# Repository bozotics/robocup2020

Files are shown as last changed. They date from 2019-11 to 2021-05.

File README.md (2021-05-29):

## PCB Design Files

View .sch and .brd files interactively on [Inventhub!](https://inventhub.io/c/bozotics/robocup2020/tree/PCB)   

Included in this repo are design files for the various PCBs we use. We designed these in EAGLE thanks to [Autodesk's free education licences](https://www.autodesk.com/education/free-software/featured). 

The libraries used unfortunately cannot be shared due to Autodesk's library.io sharing limitations, however if you would like to view it do contact us! We would be happy to send a copy of the latest version, albeit without the included 3d models (again due to the library.io limitations).

Structure of this repository:
```
.
├── Datasheets # PDFs for the various parts we use
├── PCB2k20 # Design files for our PCBs
│   ├── Layer 1, 3, 4 # for Soccer Open
│   ├── PMW3360MouseSensor # for our Mouse Sensor breakout board
│   ├── RescueLS # for Rescue Line's light sensor breakout board
│   └── TPS5430 # for the buck converter breakout board
├── TestV3_2020
└── Rescue
```
Files for previous years can be found in our [other archived repositories](https://github.com/bozotics).

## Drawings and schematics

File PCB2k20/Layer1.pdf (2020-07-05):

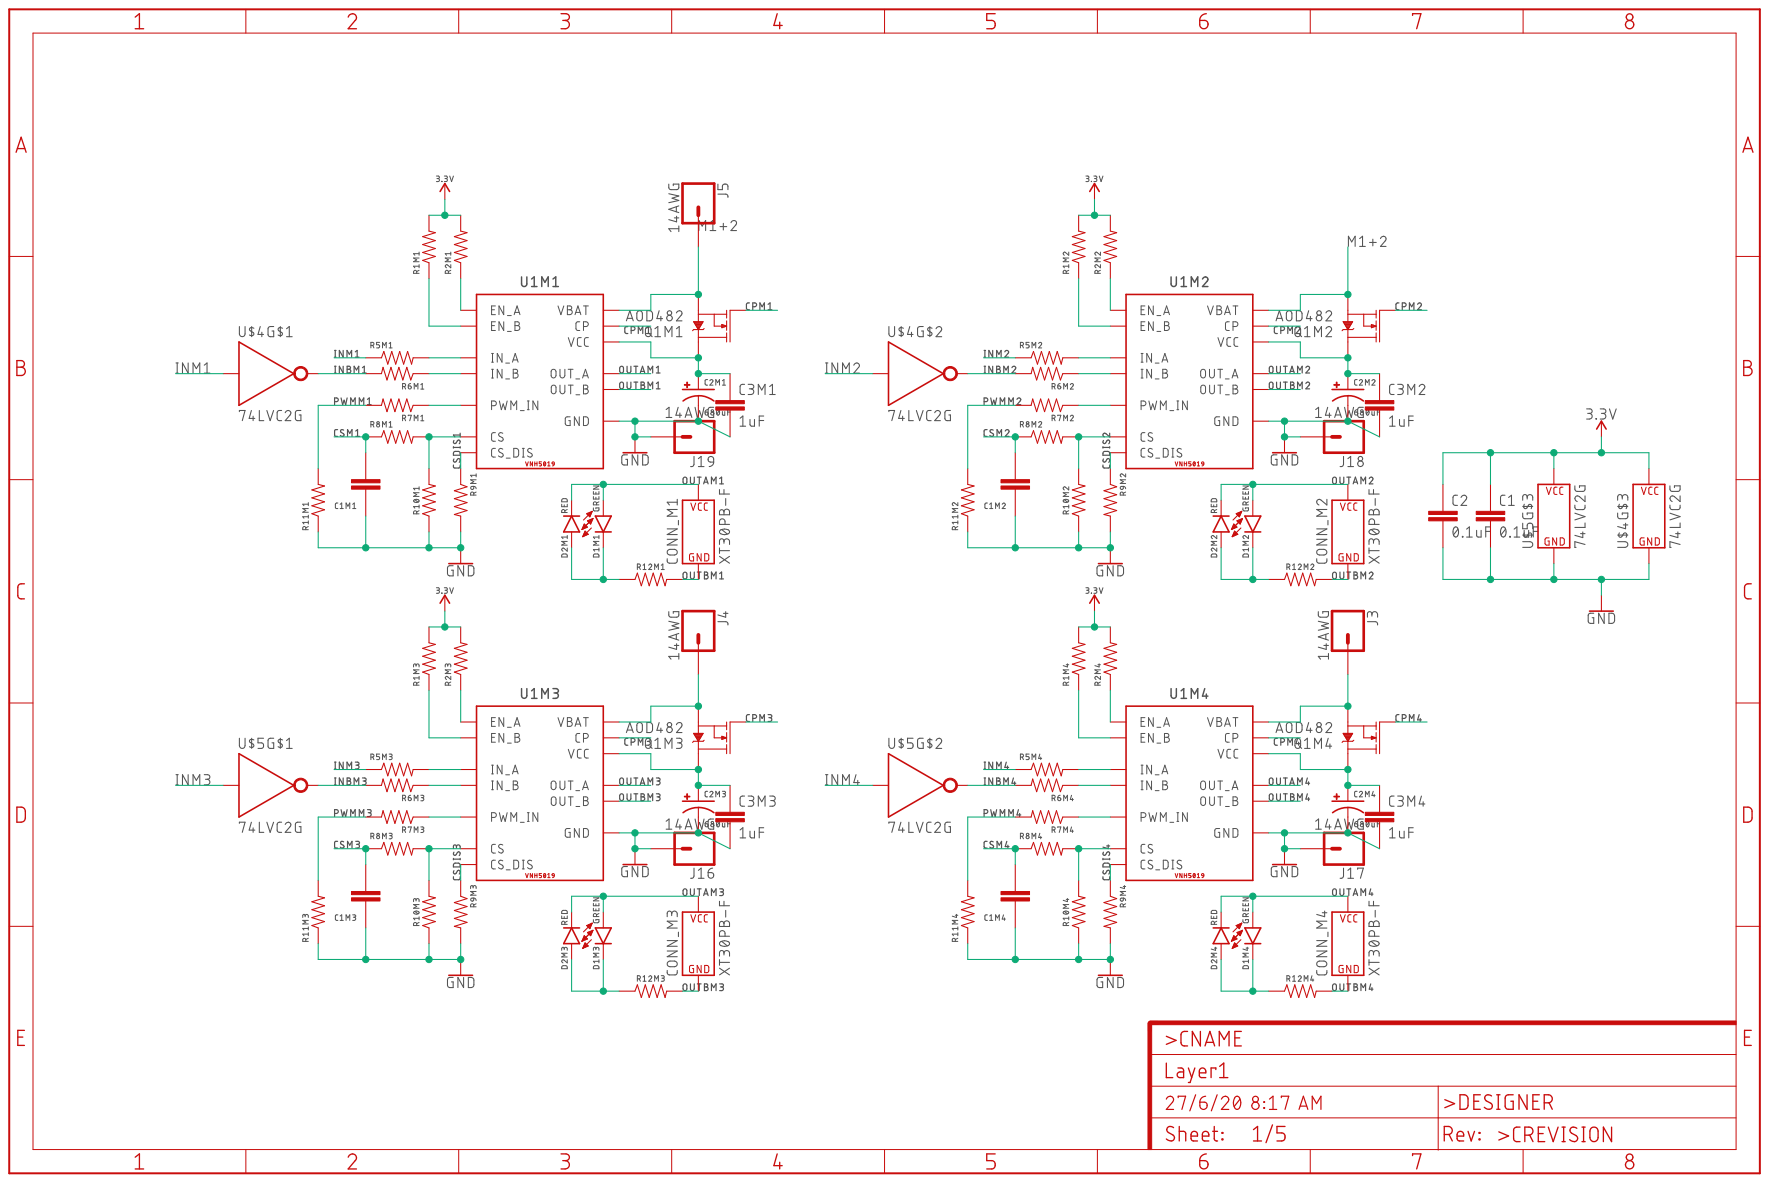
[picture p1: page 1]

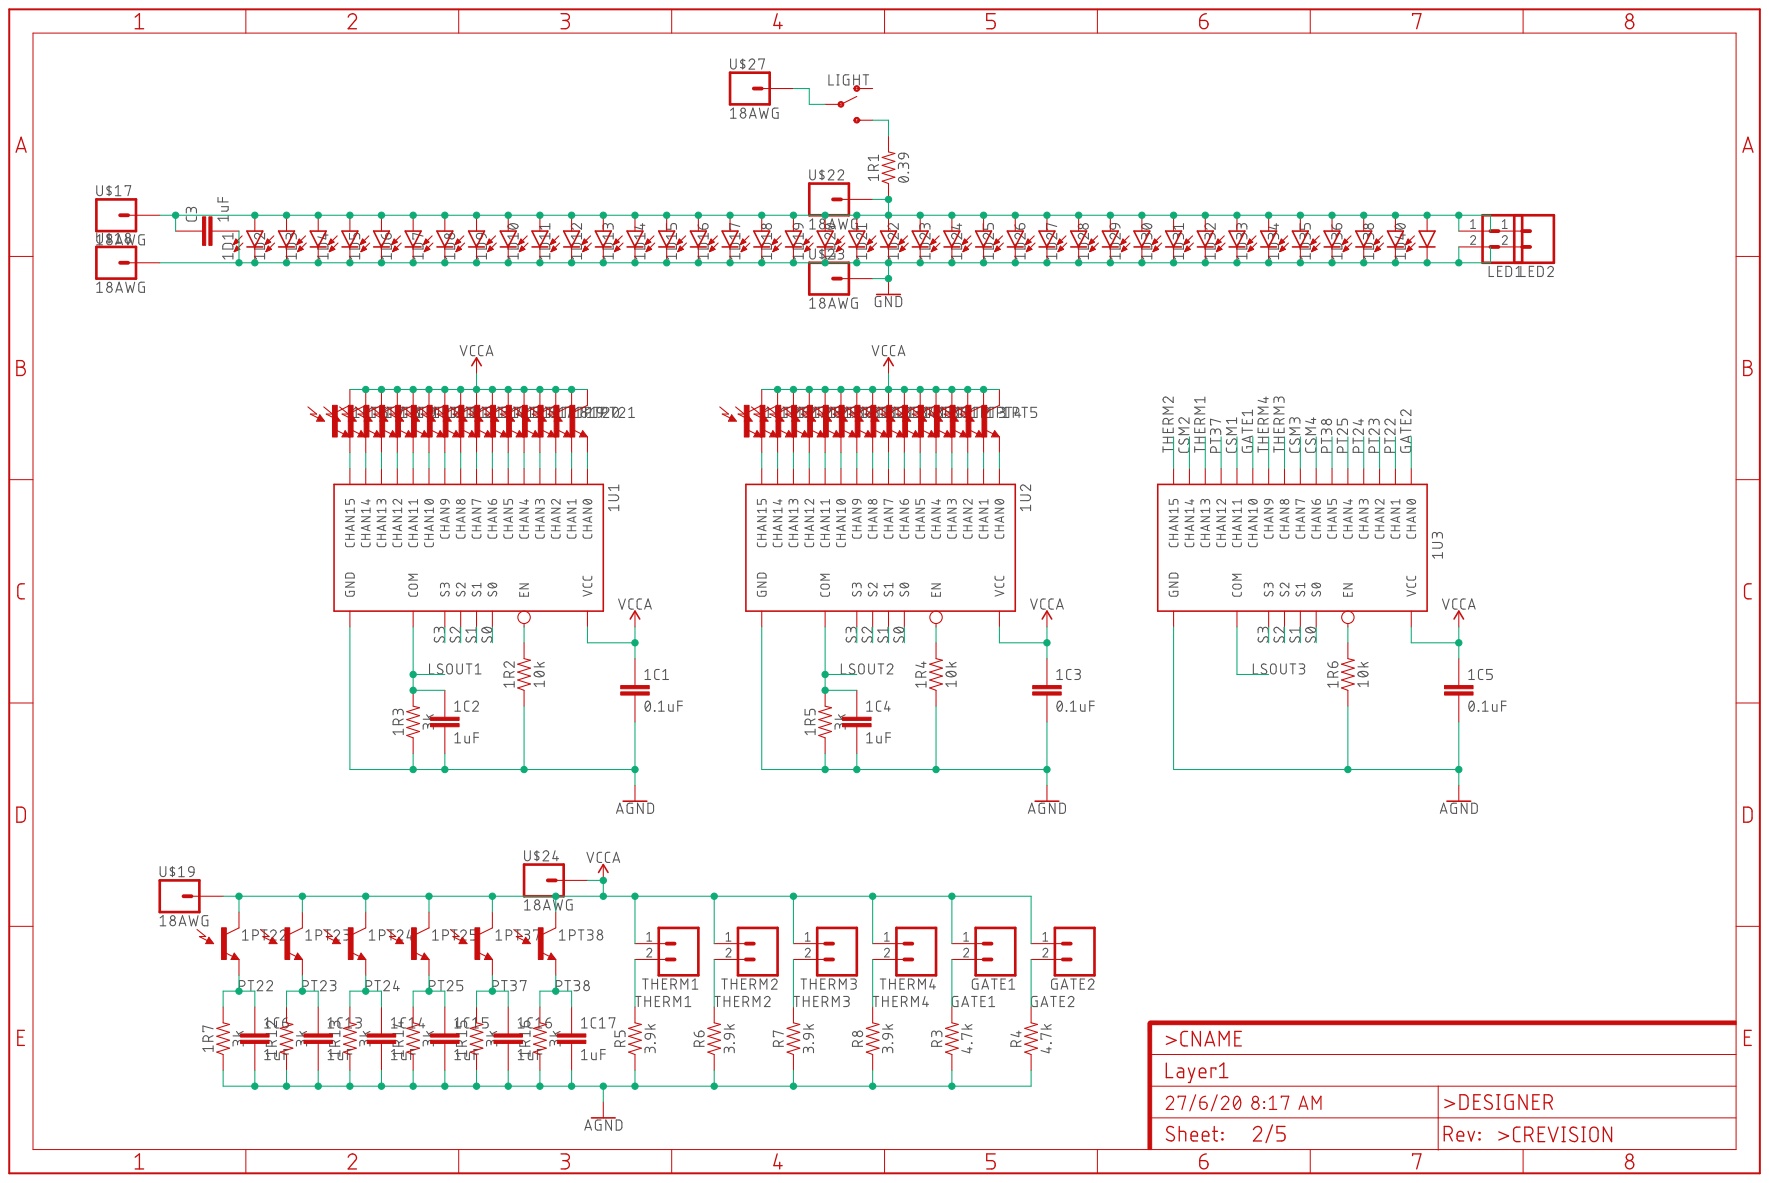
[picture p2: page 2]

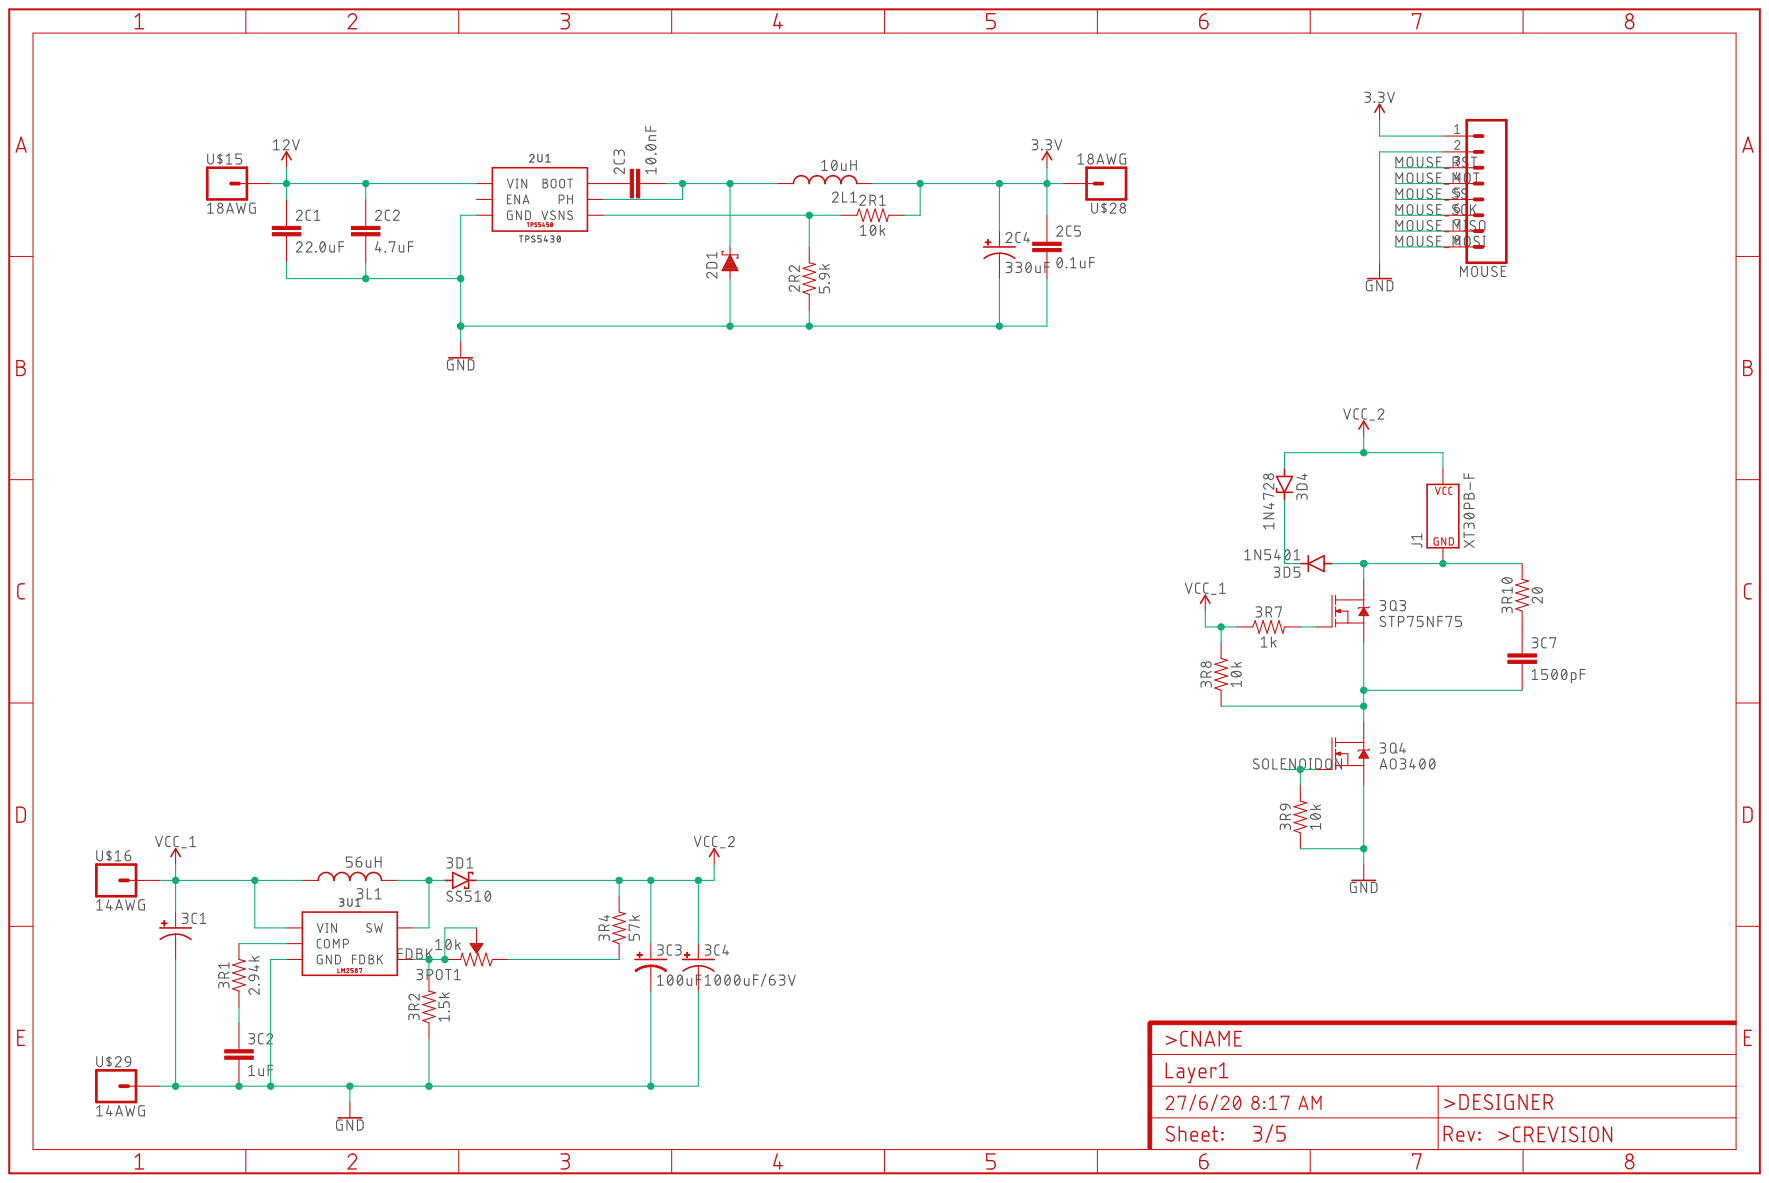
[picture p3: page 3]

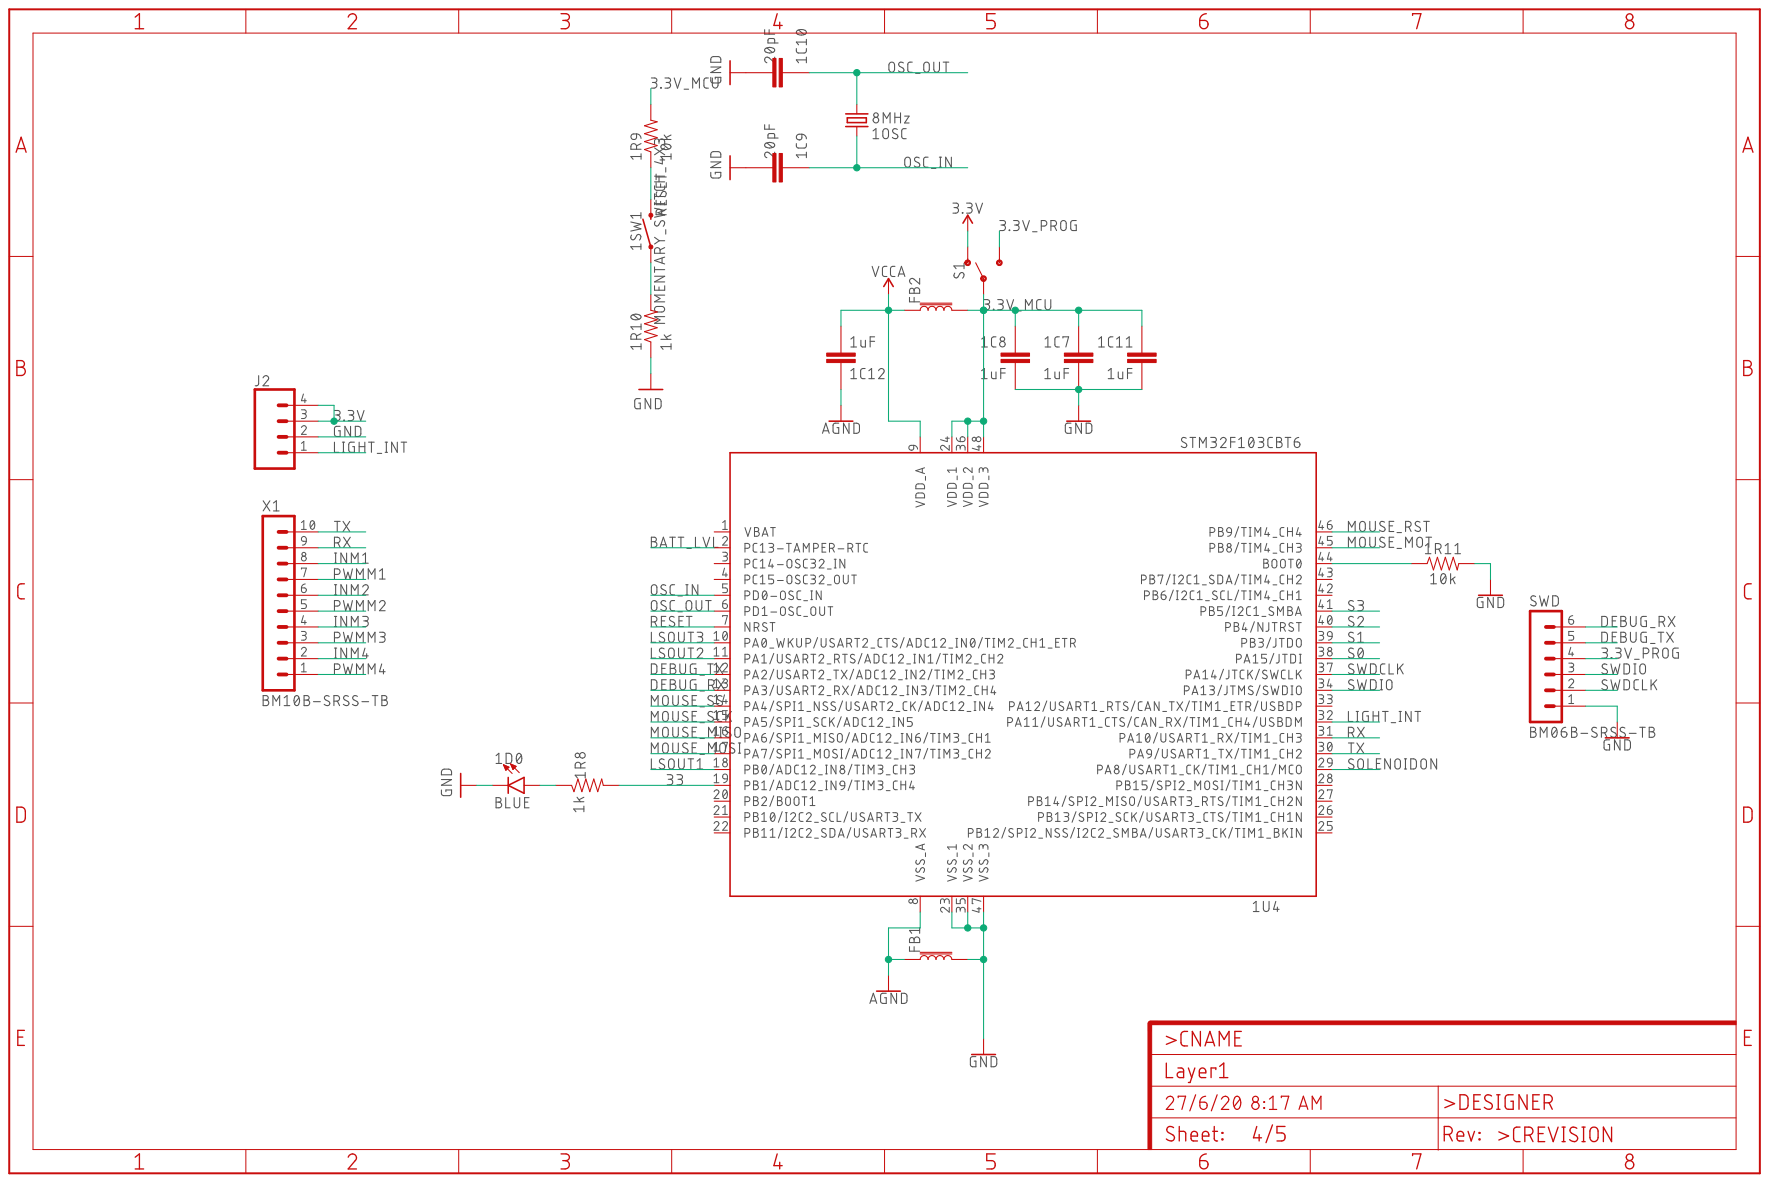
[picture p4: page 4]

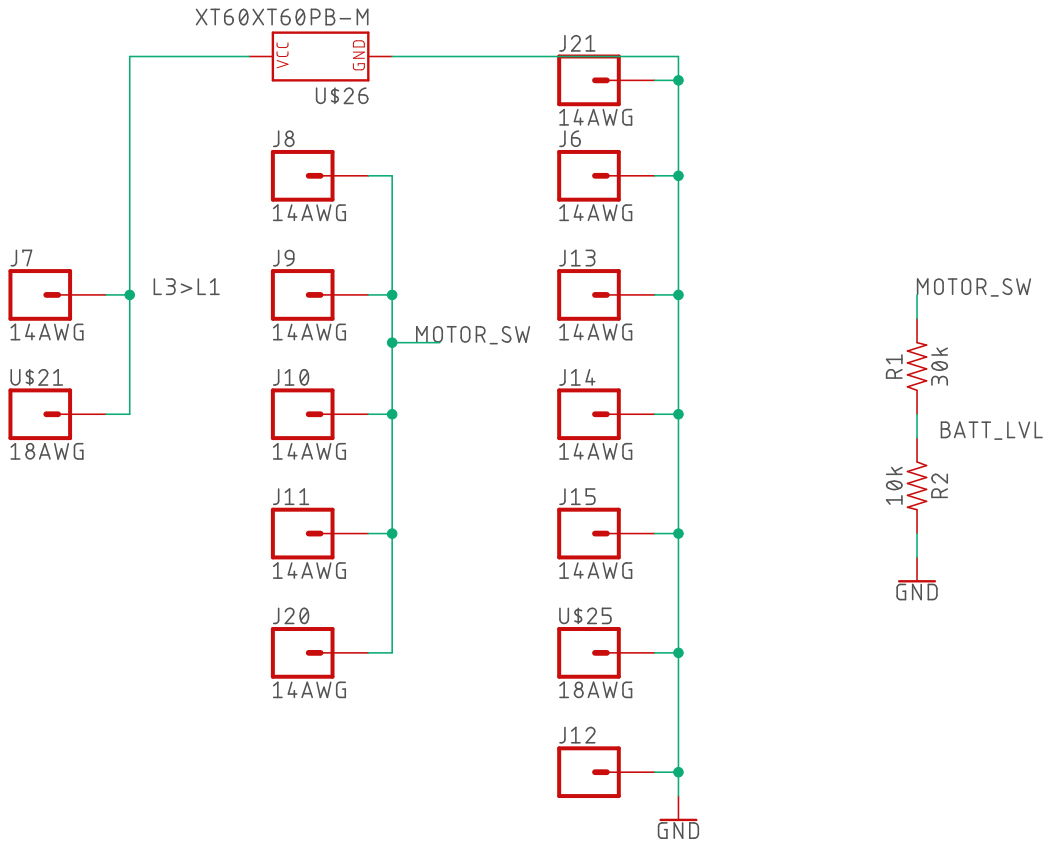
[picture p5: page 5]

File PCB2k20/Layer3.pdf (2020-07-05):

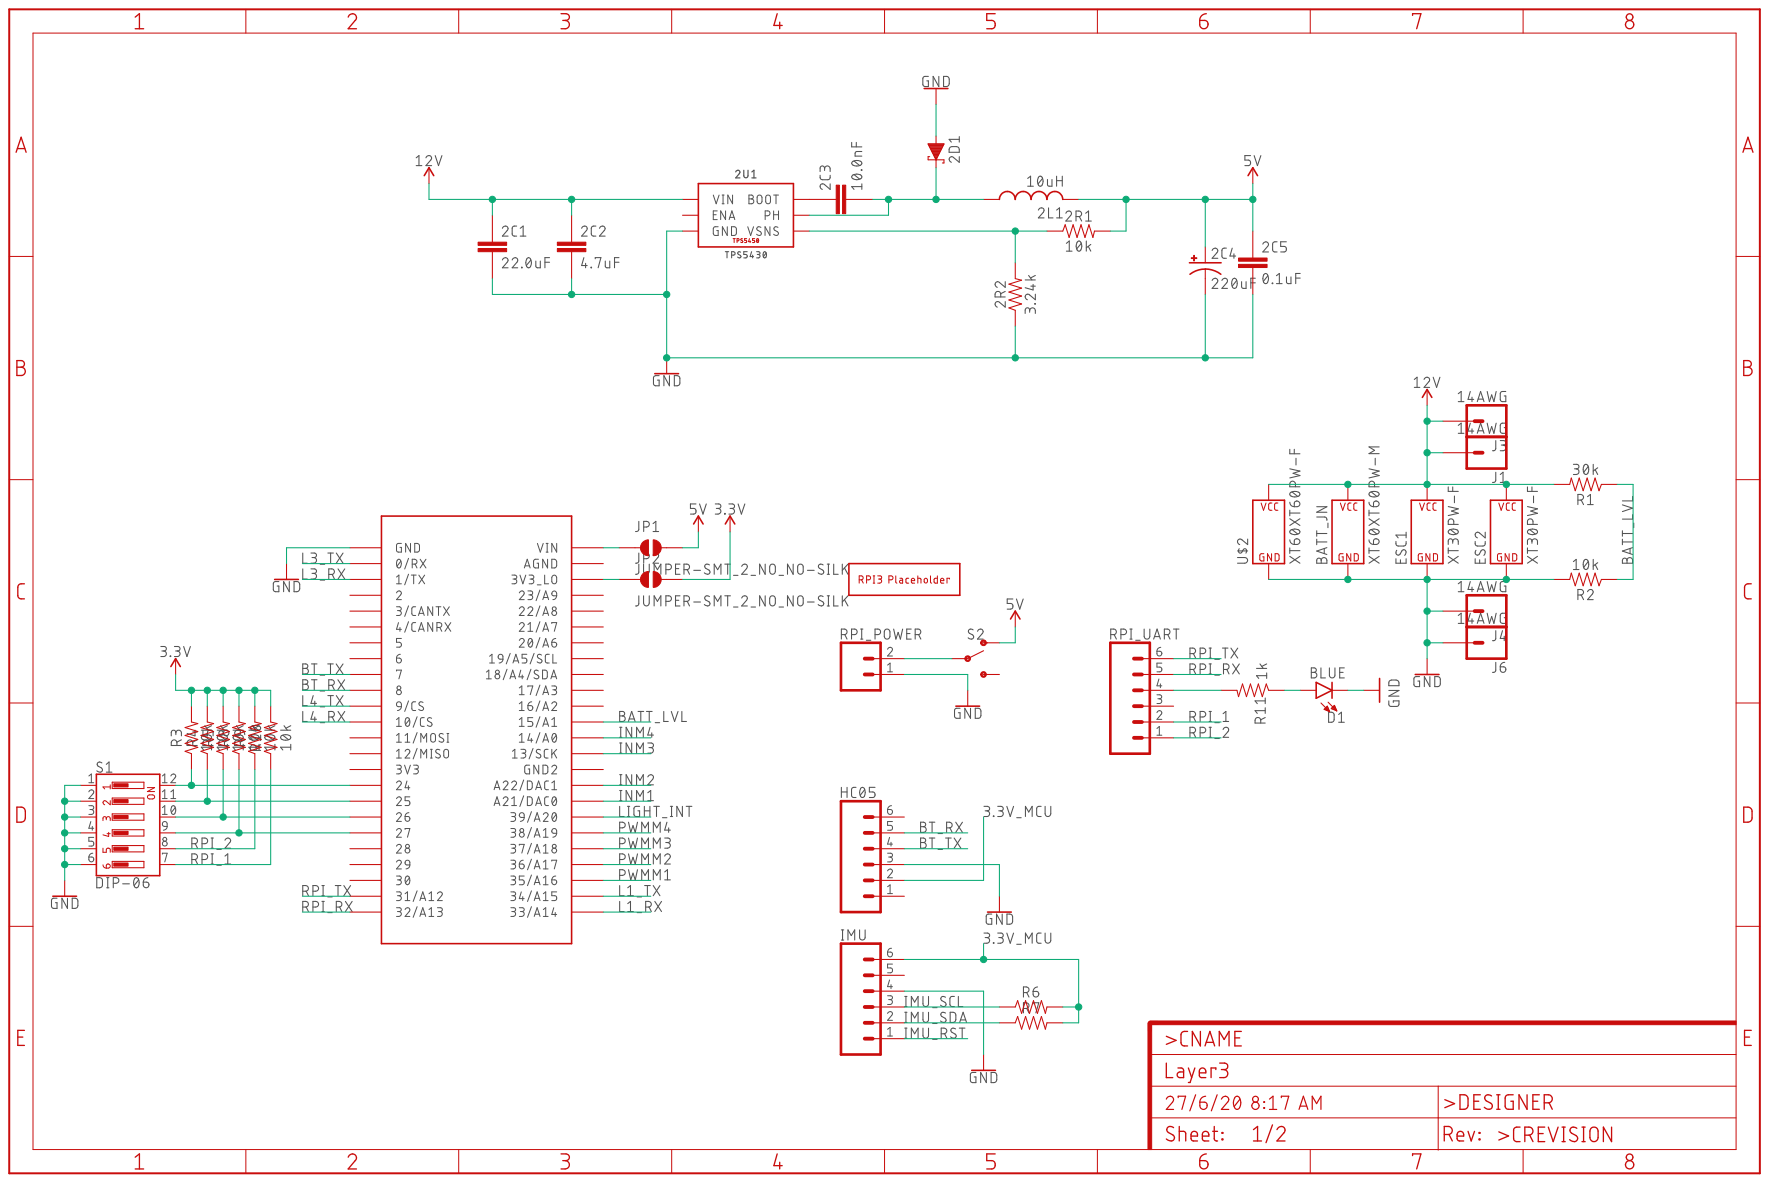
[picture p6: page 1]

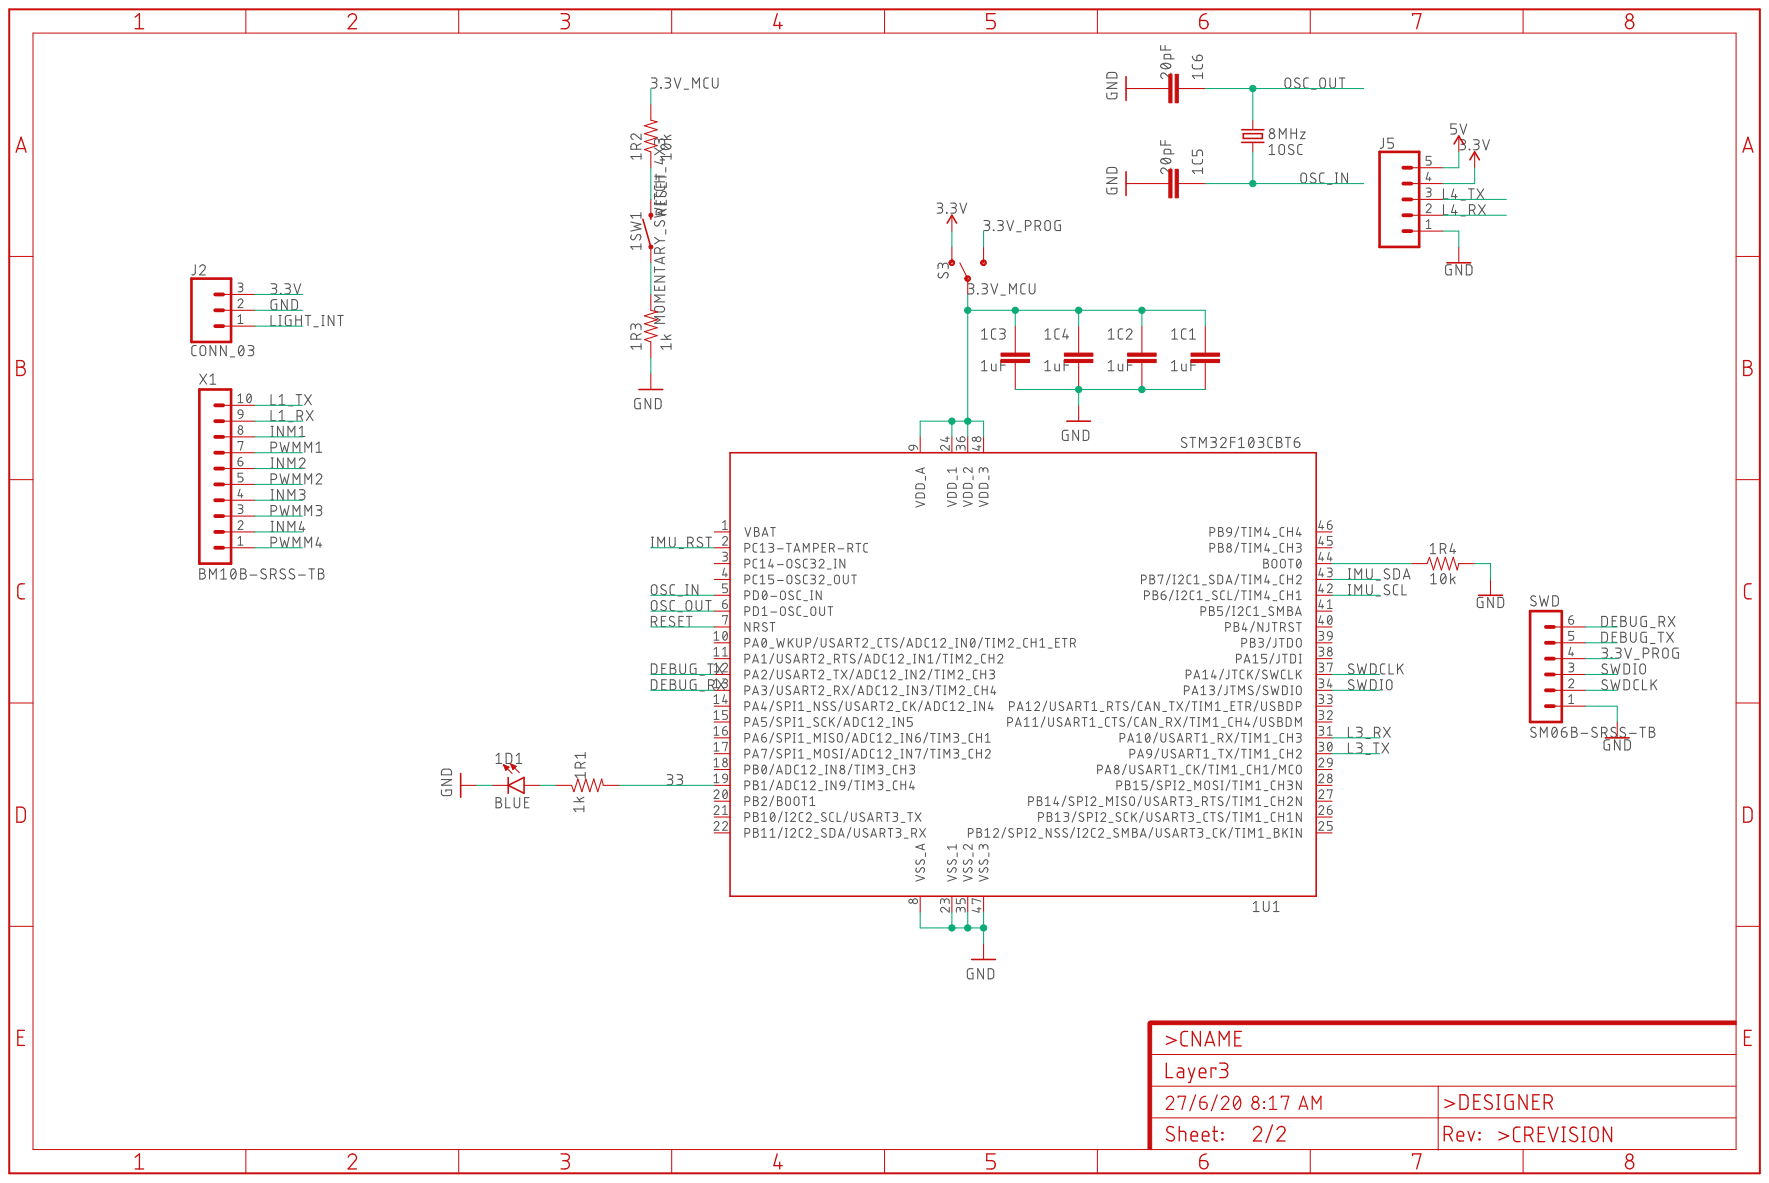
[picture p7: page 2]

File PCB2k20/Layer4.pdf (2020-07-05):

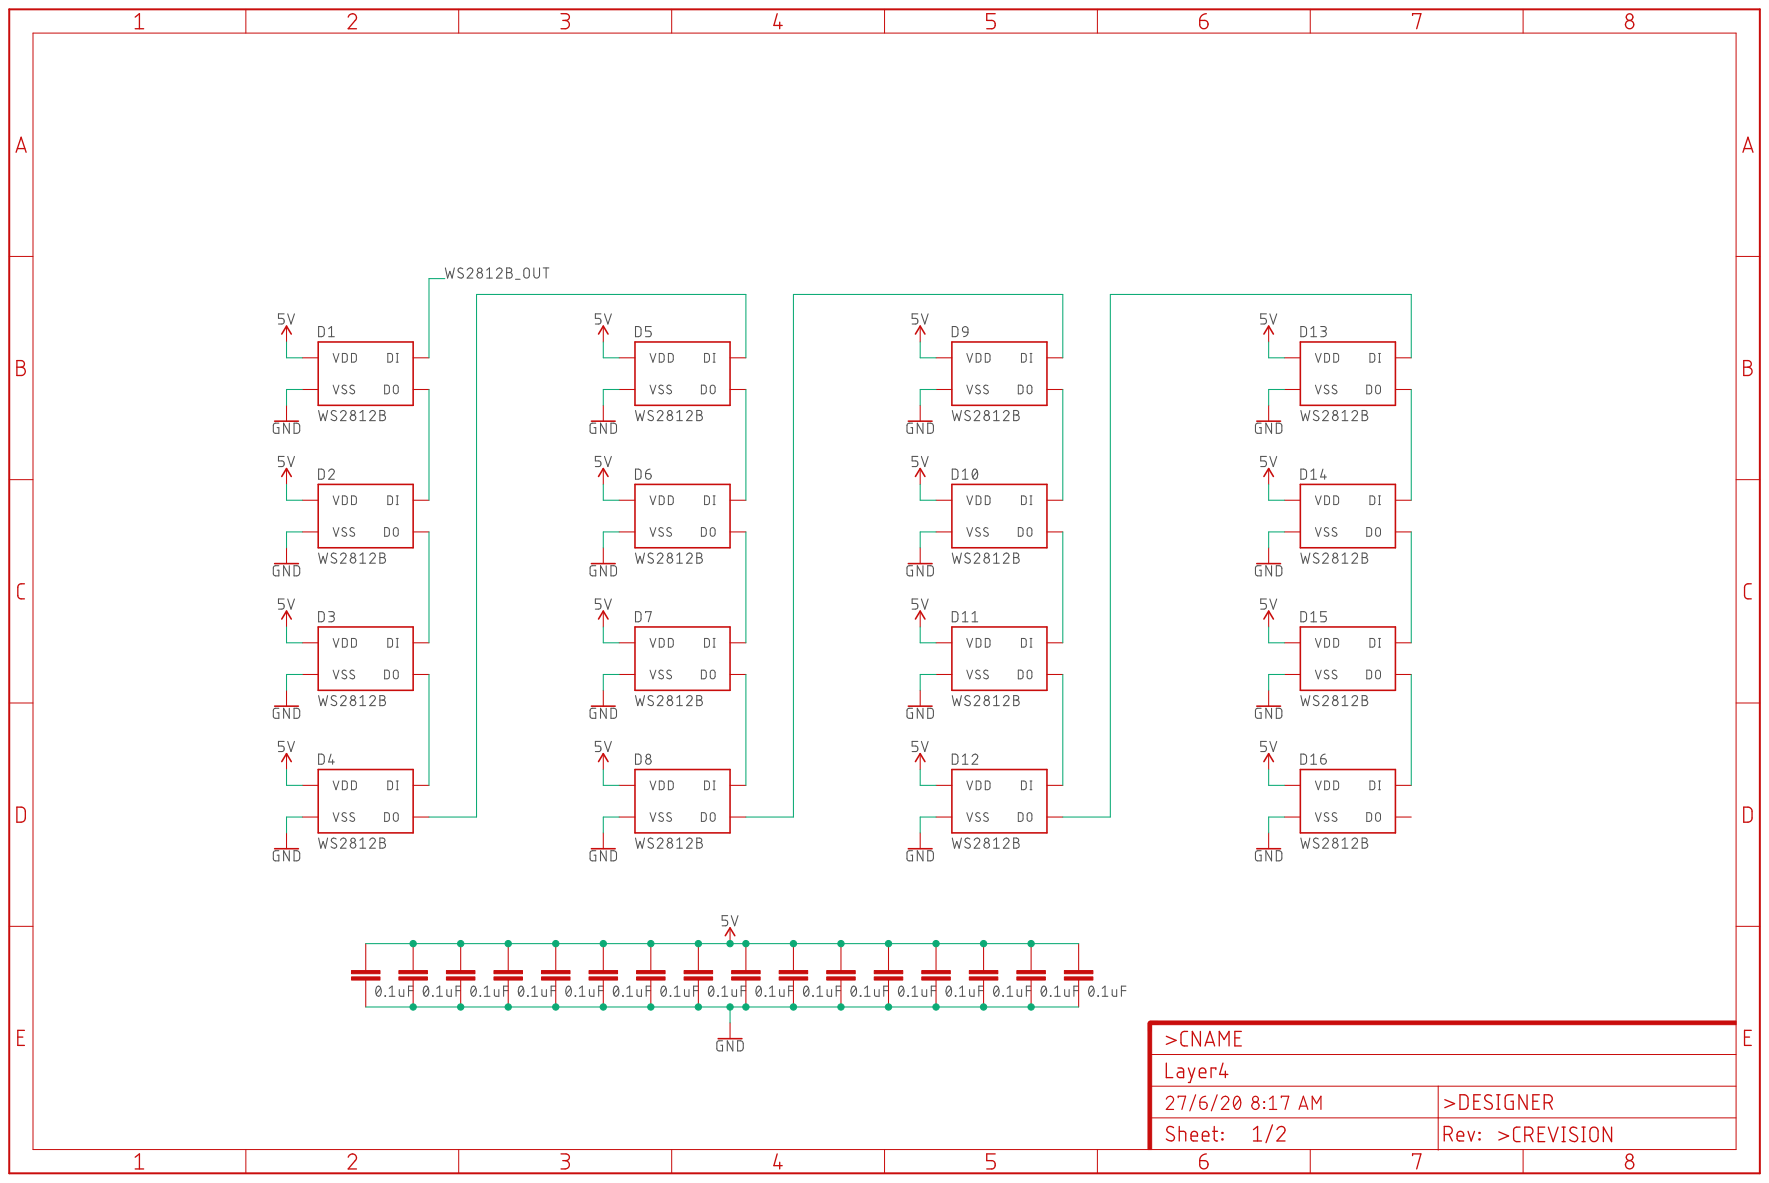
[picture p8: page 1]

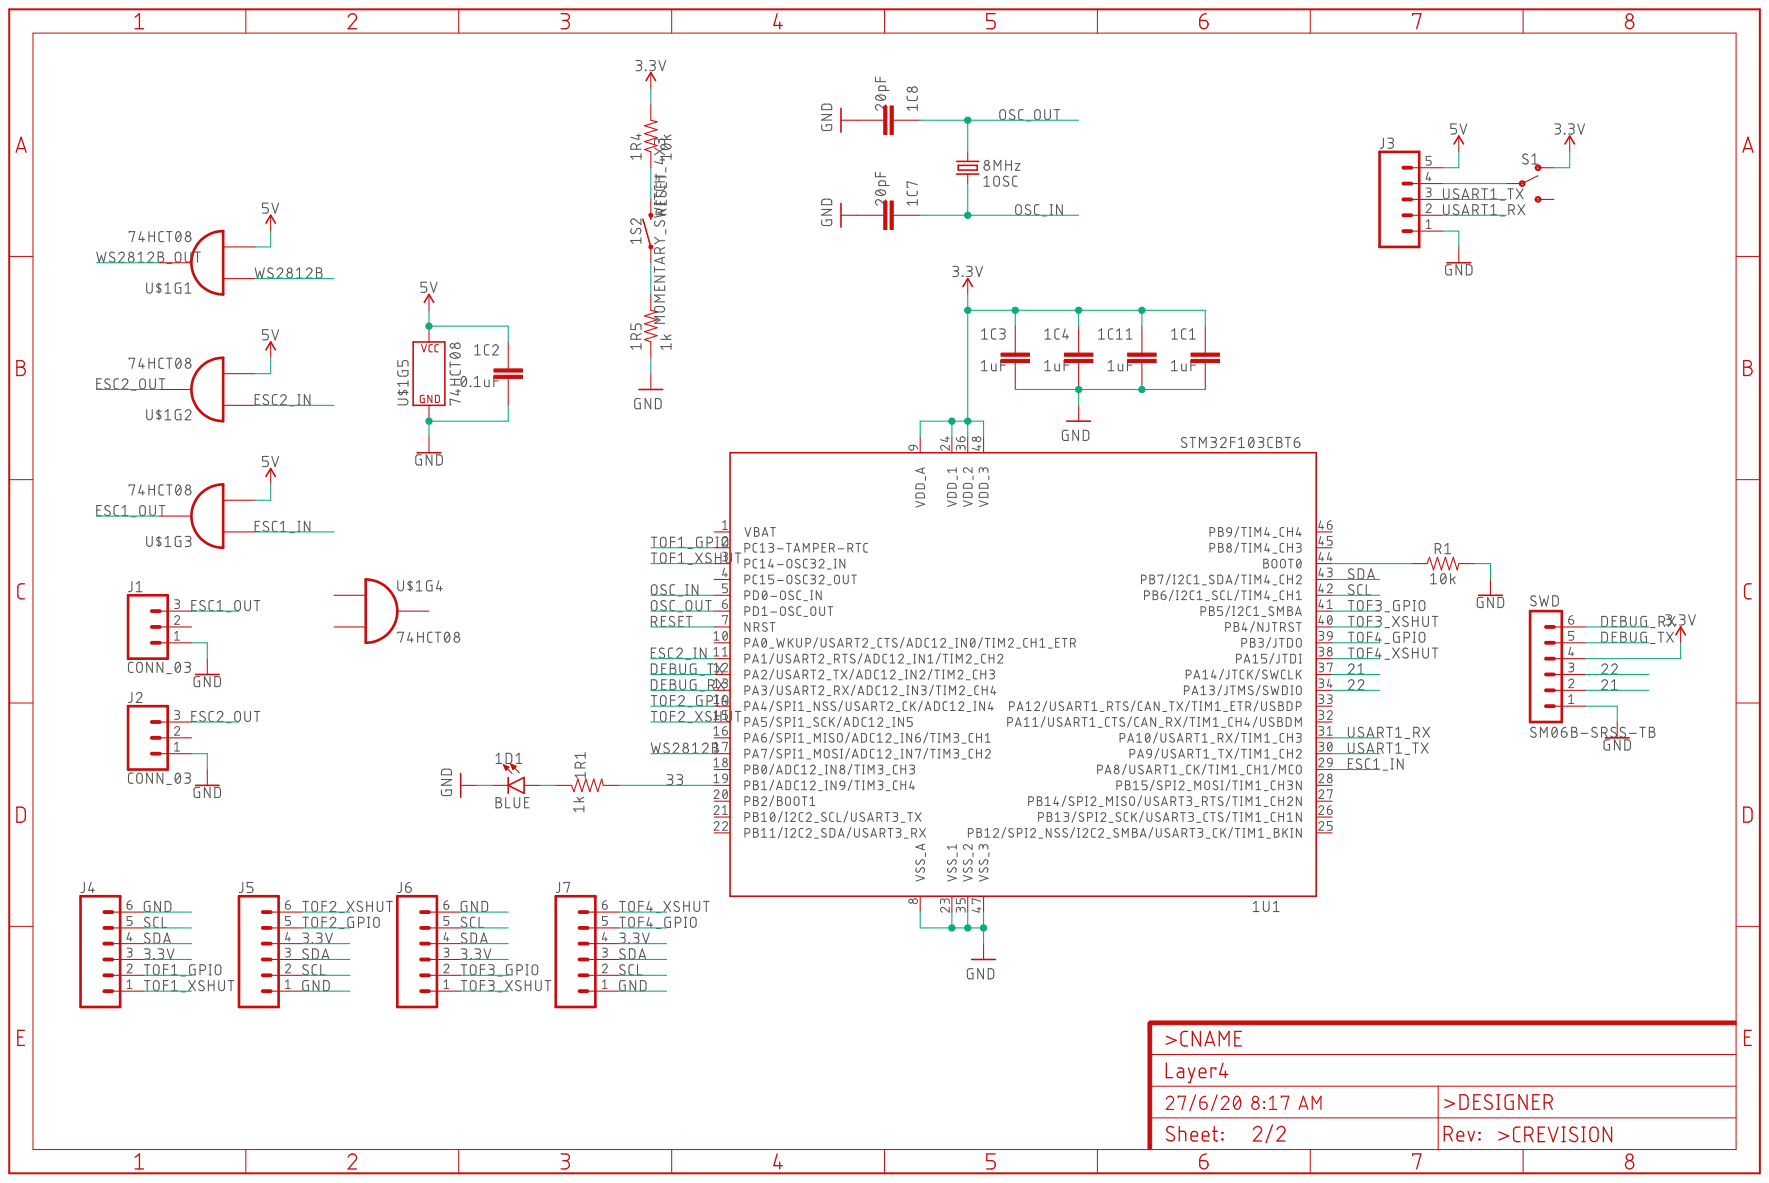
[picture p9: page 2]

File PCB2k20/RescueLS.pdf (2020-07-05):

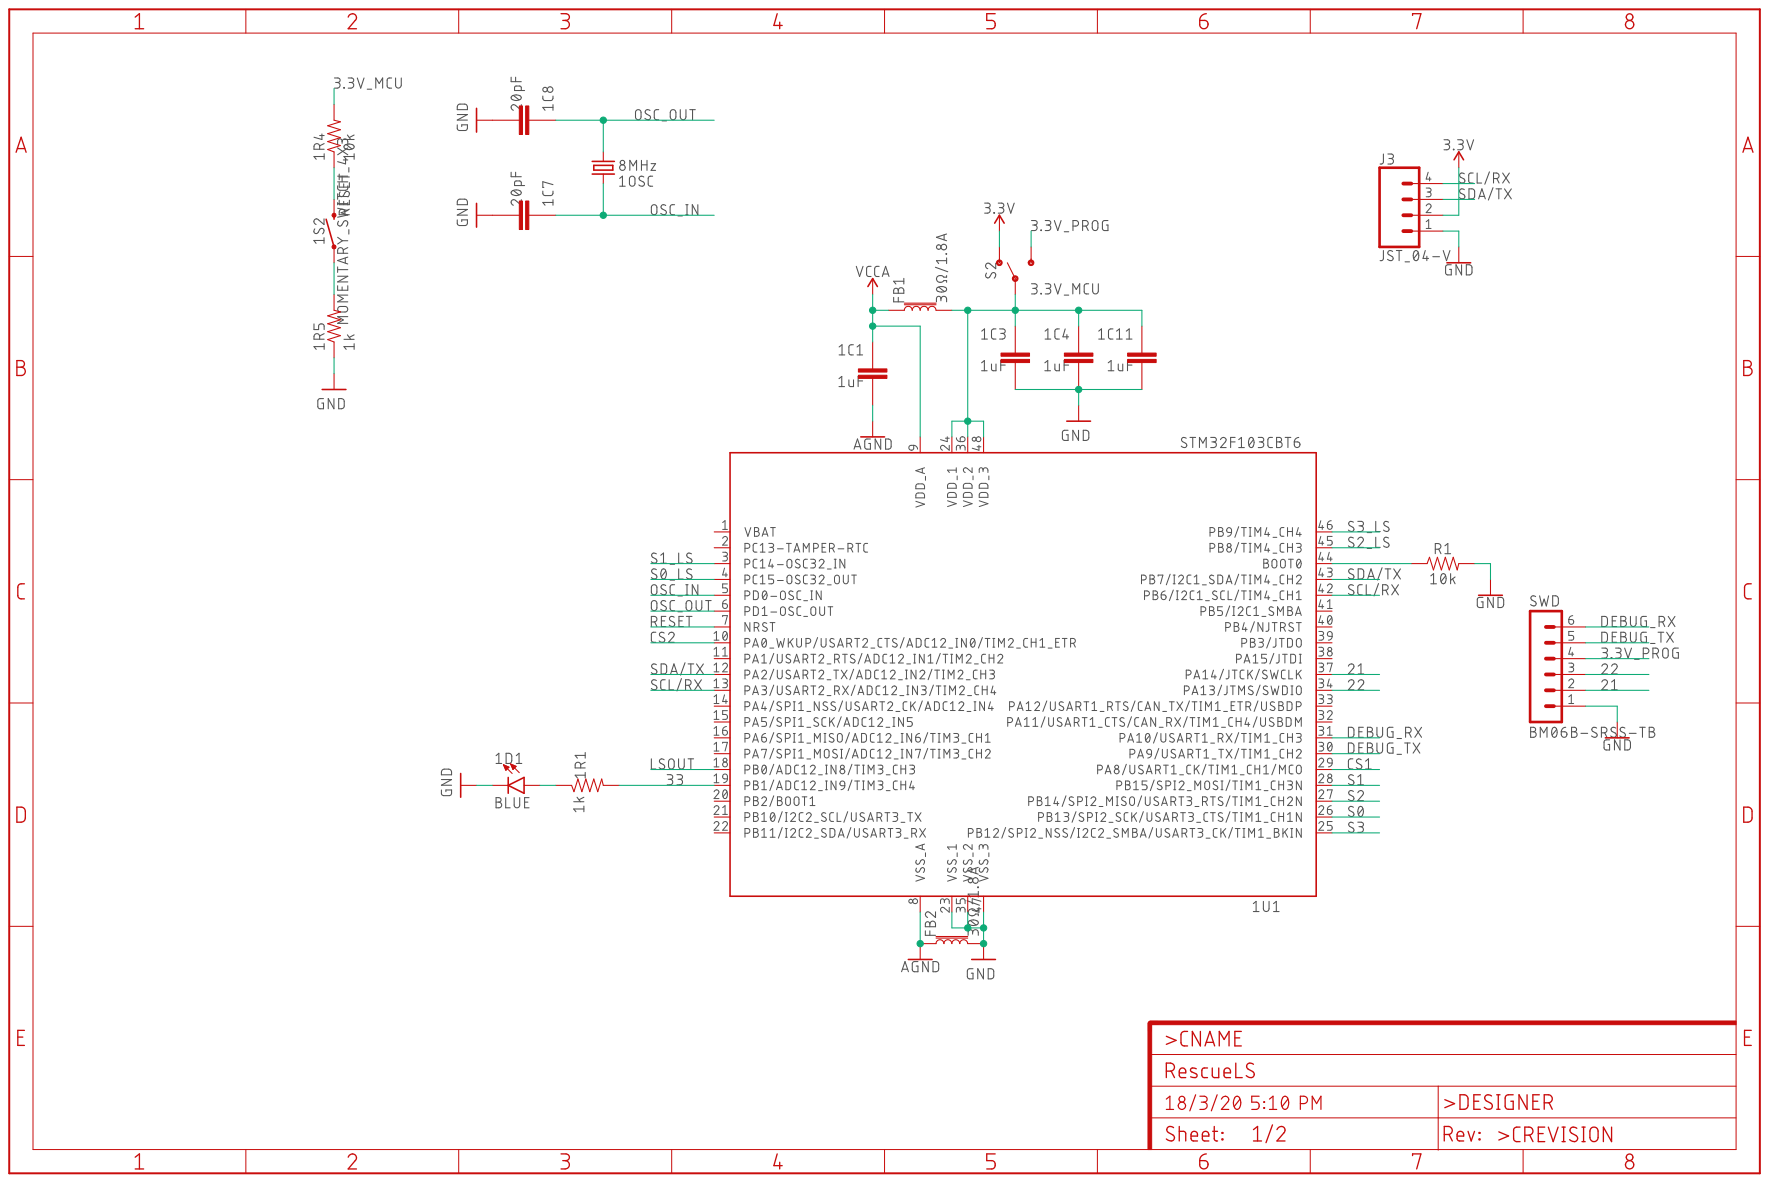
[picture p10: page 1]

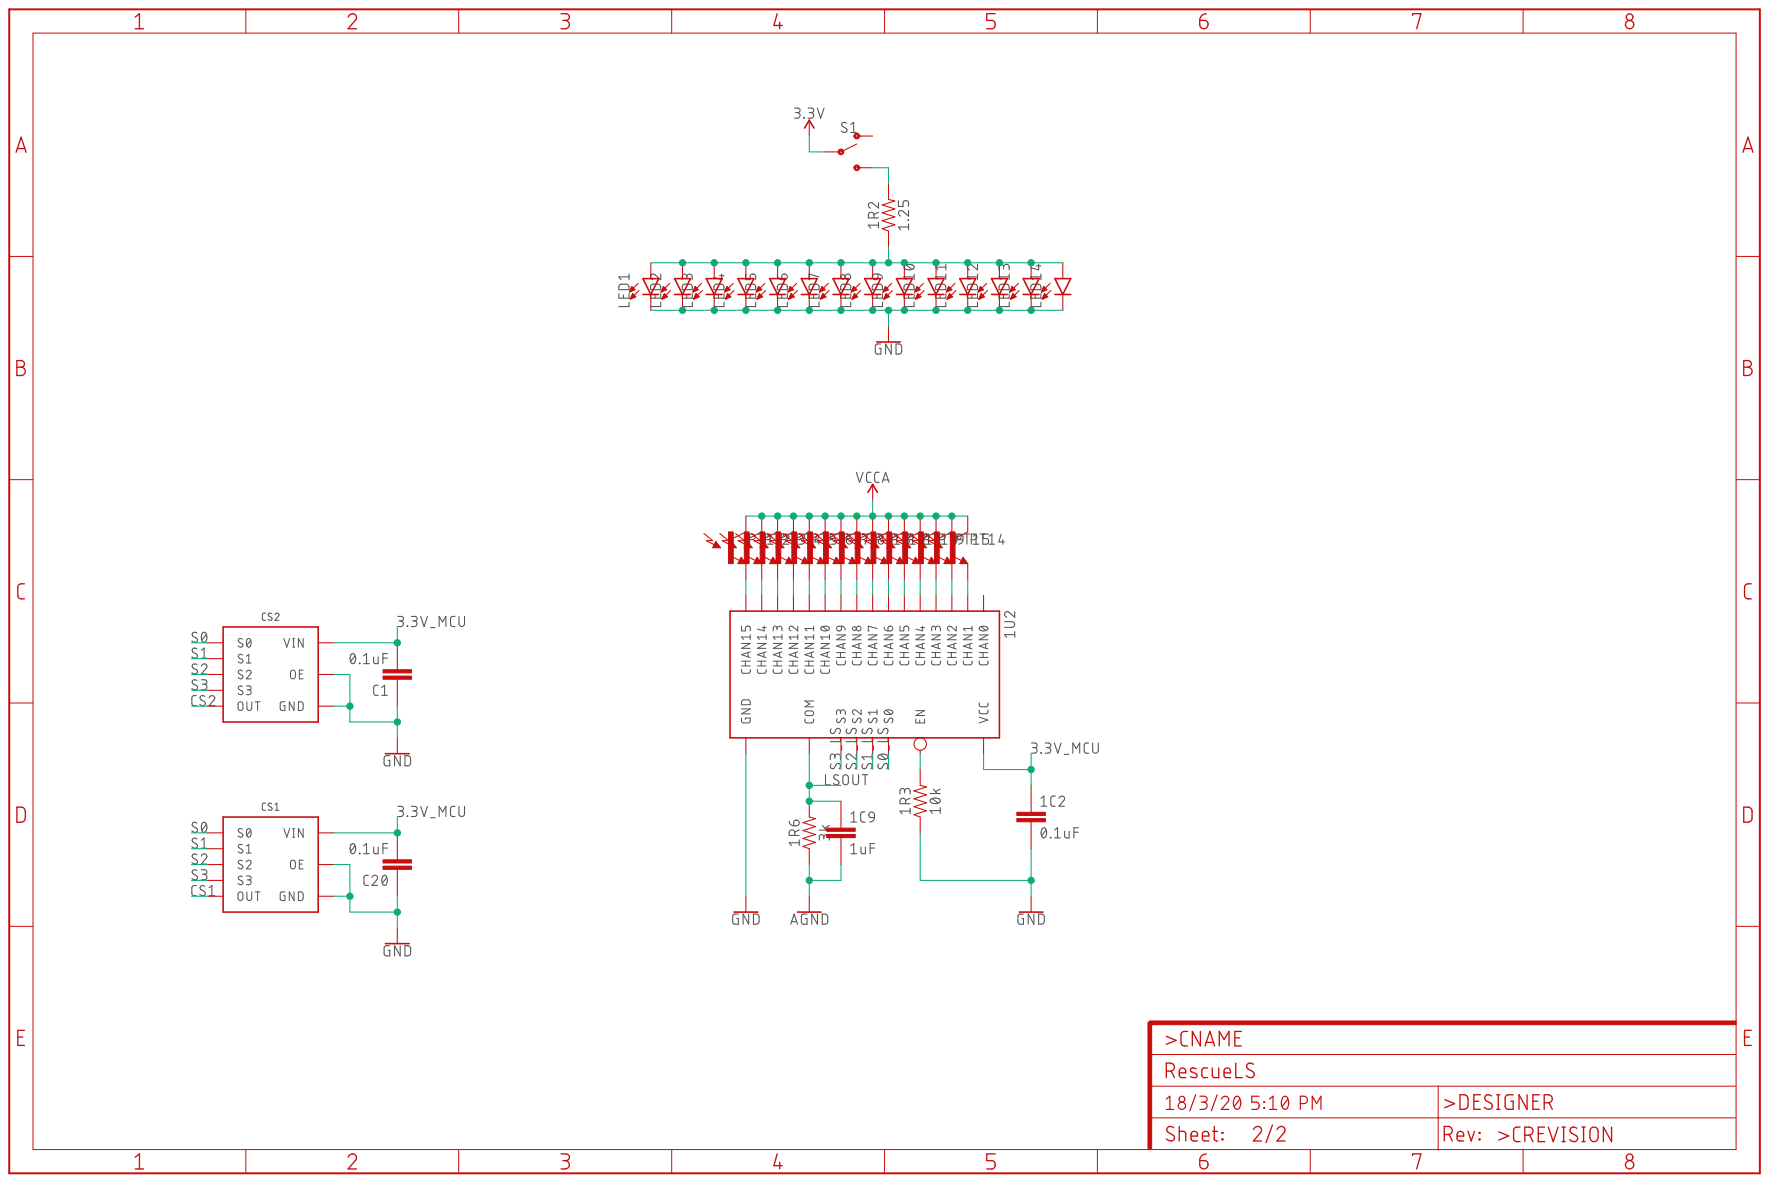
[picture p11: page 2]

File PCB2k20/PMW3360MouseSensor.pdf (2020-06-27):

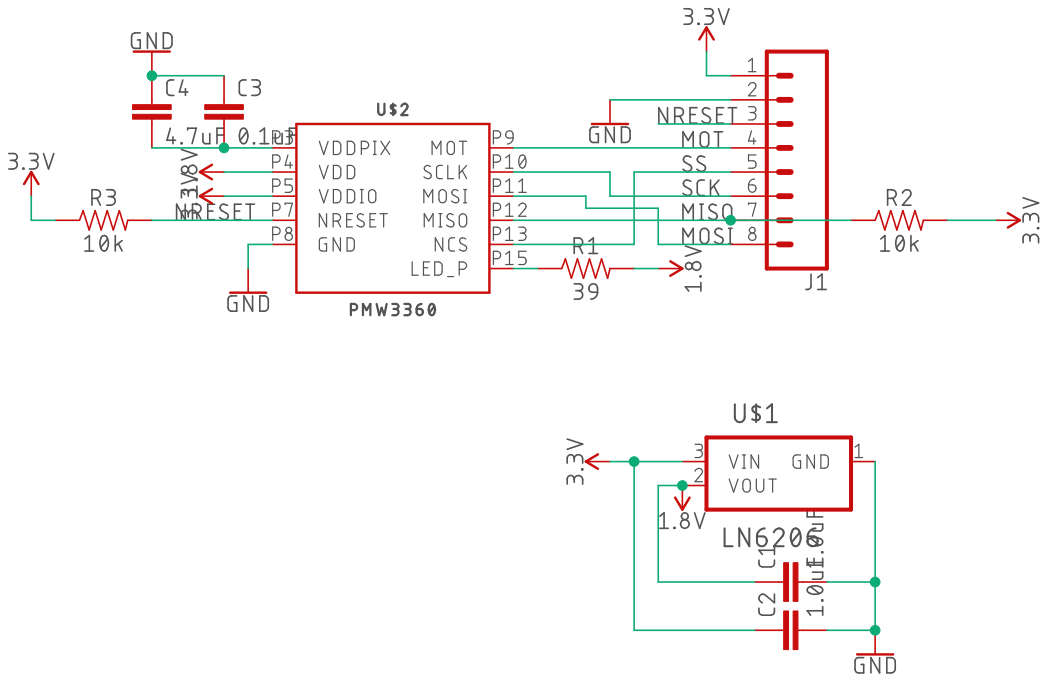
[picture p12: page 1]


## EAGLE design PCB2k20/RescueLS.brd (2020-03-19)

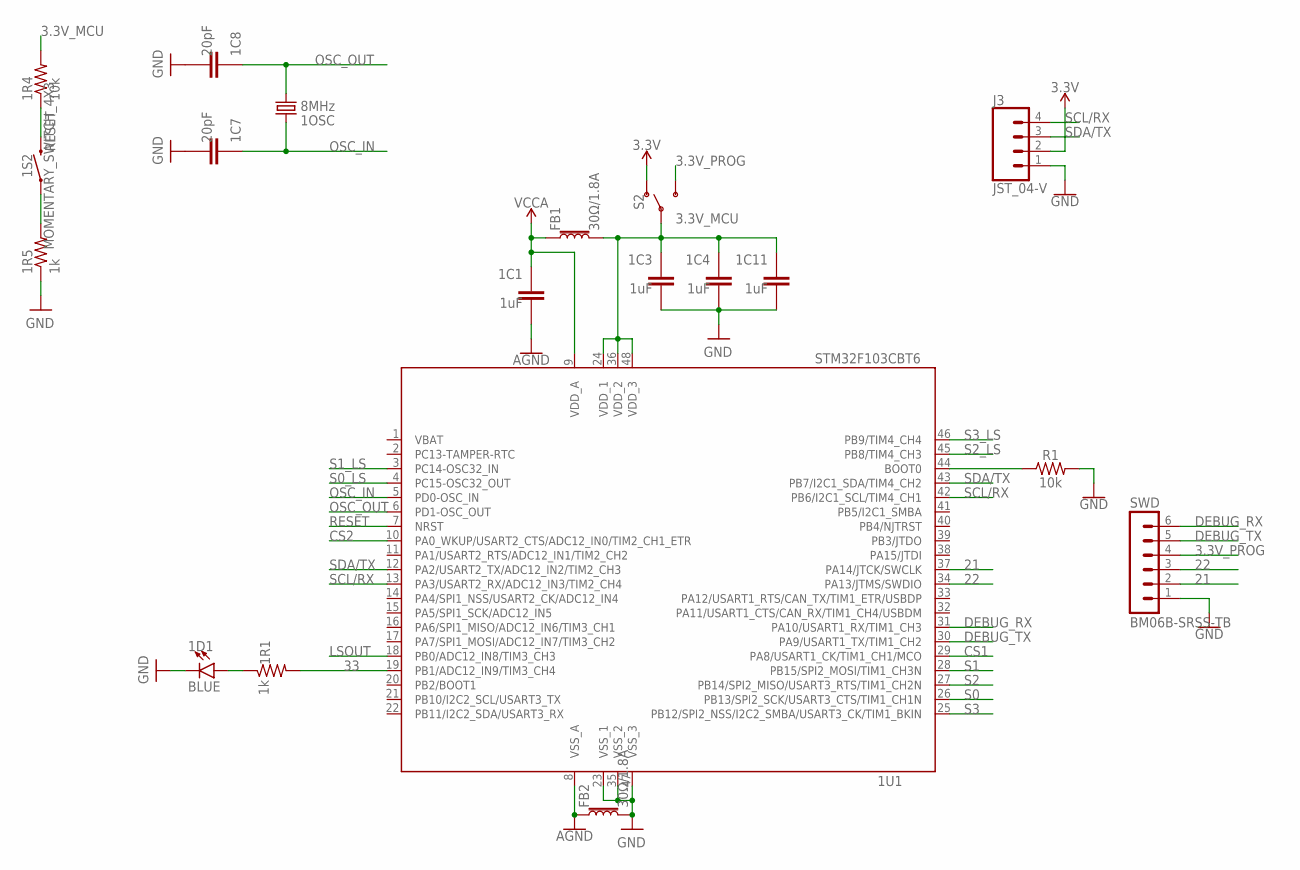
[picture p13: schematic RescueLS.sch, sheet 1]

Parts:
1C1, 1C3, 1C4, 1C11: 1uF; C0603
1C7, 1C8: 20pF; C0603
1D1: BLUE; LED-0603
1OSC: 8MHz; CRYSTAL-SMD-5X3.2-2PAD
1R1, 1R5: 1k; R0603
1R4: 10k; R0603
1S2: MOMENTARY_SWITCH_4X3
1U1: STM32F103CBT6; LQFP48
FB1, FB2: 30Ω/1.8A; 0603
J3: JST_04-V
R1: 10k; R0603
S2: SWITCH-SPDT-PTH-11.6X4.0MM-LOCK; SWITCH_SPDT_PTH_11.6X4.0MM_LOCK
SWD: BM06B-SRSS-TB

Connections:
3.3V: J3.2, S2.1 (O); also elsewhere on the board
3.3V_MCU: 1C3.1, 1C4.1, 1C11.1, 1R4.2, 1U1.24 (VDD_1), 1U1.36 (VDD_2), 1U1.48 (VDD_3), FB1.2, S2.2; also elsewhere on the board
3.3V_PROG: S2.3 (S), SWD.4
21: 1U1.37 (PA14/JTCK/SWCLK), SWD.2
22: 1U1.34 (PA13/JTMS/SWDIO), SWD.3
33: 1R1.2, 1U1.19 (PB1/ADC12_IN9/TIM3_CH4)
AGND: 1C1.2, 1U1.8 (VSS_A), FB2.1; also elsewhere on the board
CS1: 1U1.29 (PA8/USART1_CK/TIM1_CH1/MCO); also elsewhere on the board
CS2: 1U1.10 (PA0_WKUP/USART2_CTS/ADC12_IN0/TIM2_CH1_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); also elsewhere on the board
DEBUG_RX: 1U1.31 (PA10/USART1_RX/TIM1_CH3), SWD.6
DEBUG_TX: 1U1.30 (PA9/USART1_TX/TIM1_CH2), SWD.5
GND: 1C3.2, 1C4.2, 1C7.2, 1C8.2, 1C11.2, 1D1.C, 1R5.1, 1U1.23 (VSS_1), 1U1.35 (VSS_2), 1U1.47 (VSS_3), FB2.2, J3.1, R1.2, SWD.1; also elsewhere on the board
LSOUT: 1U1.18 (PB0/ADC12_IN8/TIM3_CH3); also elsewhere on the board
unnamed: 1D1.A, 1R1.1
unnamed: 1R5.2, 1S2.P$1 (1)
unnamed: 1U1.44 (BOOT0), R1.1
OSC_IN: 1C7.1, 1OSC.P$2 (2), 1U1.5 (PD0-OSC_IN)
OSC_OUT: 1C8.1, 1OSC.P$1 (1), 1U1.6 (PD1-OSC_OUT)
RESET: 1R4.1, 1S2.P$2 (2), 1U1.7 (NRST)
S0: 1U1.26 (PB13/SPI2_SCK/USART3_CTS/TIM1_CH1N); also elsewhere on the board
S0_LS: 1U1.4 (PC15-OSC32_OUT); also elsewhere on the board
S1: 1U1.28 (PB15/SPI2_MOSI/TIM1_CH3N); also elsewhere on the board
S1_LS: 1U1.3 (PC14-OSC32_IN); also elsewhere on the board
S2: 1U1.27 (PB14/SPI2_MISO/USART3_RTS/TIM1_CH2N); also elsewhere on the board
S2_LS: 1U1.45 (PB8/TIM4_CH3); also elsewhere on the board
S3: 1U1.25 (PB12/SPI2_NSS/I2C2_SMBA/USART3_CK/TIM1_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); also elsewhere on the board
S3_LS: 1U1.46 (PB9/TIM4_CH4); also elsewhere on the board
SCL/RX: 1U1.13 (PA3/USART2_RX/ADC12_IN3/TIM2_CH4), 1U1.42 (PB6/I2C1_SCL/TIM4_CH1), J3.4
SDA/TX: 1U1.12 (PA2/USART2_TX/ADC12_IN2/TIM2_CH3), 1U1.43 (PB7/I2C1_SDA/TIM4_CH2), J3.3
VBAT: 1U1.1 (VBAT)
VCCA: 1C1.1, 1U1.9 (VDD_A), FB1.1; also elsewhere on the board

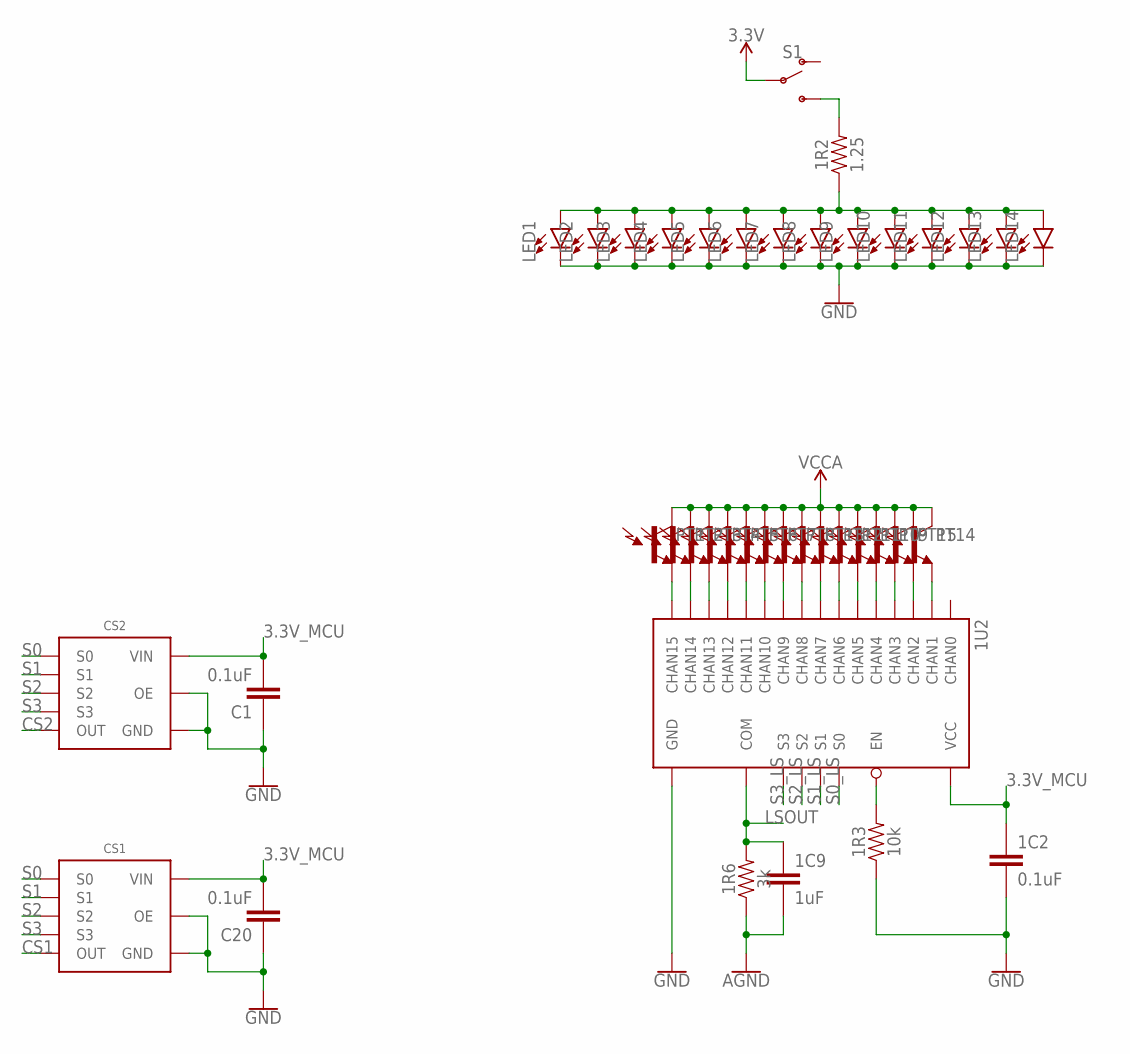
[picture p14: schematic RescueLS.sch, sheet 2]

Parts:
1C2: 0.1uF; C0603
1C9: 1uF; C0603
1R2: 1.25; R0603
1R3: 10k; R0603
1R6: 3k; R0603
1U2: 74HC4067; SOIC-24
C1, C20: 0.1uF; C0603
CS1, CS2: TCS3200; SOIC-8
LED1, LED2, LED3, LED4, LED5, LED6, LED7, LED8, LED9, LED10, LED11, LED12, LED13, LED14: 3528LED; 3528
PT1, PT2, PT3, PT4, PT5, PT6, PT7, PT8, PT9, PT10, PT11, PT12, PT13, PT14, PT15: LIGHT_SENSORALS; ALS-PT19
S1: SWITCH-SPDT-PTH-11.6X4.0MM-LOCK; SWITCH_SPDT_PTH_11.6X4.0MM_LOCK

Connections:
3.3V: S1.2; also elsewhere on the board
3.3V_MCU: 1C2.1, 1U2.P24 (VCC), C1.2, C20.2, CS1.5 (VIN), CS2.5 (VIN); also elsewhere on the board
AGND: 1C9.2, 1R6.1; also elsewhere on the board
CS1: CS1.6 (OUT); also elsewhere on the board
CS2: CS2.6 (OUT); also elsewhere on the board
GND: 1C2.2, 1R3.1, 1U2.P12 (GND), C1.1, C20.1, CS1.3 (OE), CS1.4 (GND), CS2.3 (OE), CS2.4 (GND), LED1.C, LED2.C, LED3.C, LED4.C, LED5.C, LED6.C, LED7.C, LED8.C, LED9.C, LED10.C, LED11.C, LED12.C, LED13.C, LED14.C; also elsewhere on the board
LSOUT: 1C9.1, 1R6.2, 1U2.P1 (COM); also elsewhere on the board
unnamed: 1U2.P8 (CHAN1), PT14.E (E1)
unnamed: 1R2.1, LED1.A, LED2.A, LED3.A, LED4.A, LED5.A, LED6.A, LED7.A, LED8.A, LED9.A, LED10.A, LED11.A, LED12.A, LED13.A, LED14.A
unnamed: 1R2.2, S1.3 (S)
unnamed: 1U2.P6 (CHAN3), PT9.E (E1)
unnamed: 1U2.P5 (CHAN4), PT10.E (E1)
unnamed: 1U2.P4 (CHAN5), PT11.E (E1)
unnamed: 1U2.P3 (CHAN6), PT12.E (E1)
unnamed: 1U2.P2 (CHAN7), PT13.E (E1)
unnamed: 1U2.P7 (CHAN2), PT15.E (E1)
unnamed: 1R3.2, 1U2.P15 (EN)
unnamed: 1U2.P16 (CHAN15), PT1.E (E1)
unnamed: 1U2.P17 (CHAN14), PT2.E (E1)
unnamed: 1U2.P18 (CHAN13), PT3.E (E1)
unnamed: 1U2.P19 (CHAN12), PT4.E (E1)
unnamed: 1U2.P20 (CHAN11), PT5.E (E1)
unnamed: 1U2.P21 (CHAN10), PT6.E (E1)
unnamed: 1U2.P22 (CHAN9), PT7.E (E1)
unnamed: 1U2.P23 (CHAN8), PT8.E (E1)
S0: CS1.1 (S0), CS2.1 (S0); also elsewhere on the board
S0_LS: 1U2.P10 (S0); also elsewhere on the board
S1: CS1.2 (S1), CS2.2 (S1); also elsewhere on the board
S1_LS: 1U2.P11 (S1); also elsewhere on the board
S2: CS1.7 (S2), CS2.7 (S2); also elsewhere on the board
S2_LS: 1U2.P14 (S2); also elsewhere on the board
S3: CS1.8 (S3), CS2.8 (S3); also elsewhere on the board
S3_LS: 1U2.P13 (S3); also elsewhere on the board
VCCA: PT1.C (C1), PT2.C (C1), PT3.C (C1), PT4.C (C1), PT5.C (C1), PT6.C (C1), PT7.C (C1), PT8.C (C1), PT9.C (C1), PT10.C (C1), PT11.C (C1), PT12.C (C1), PT13.C (C1), PT14.C (C1), PT15.C (C1); also elsewhere on the board

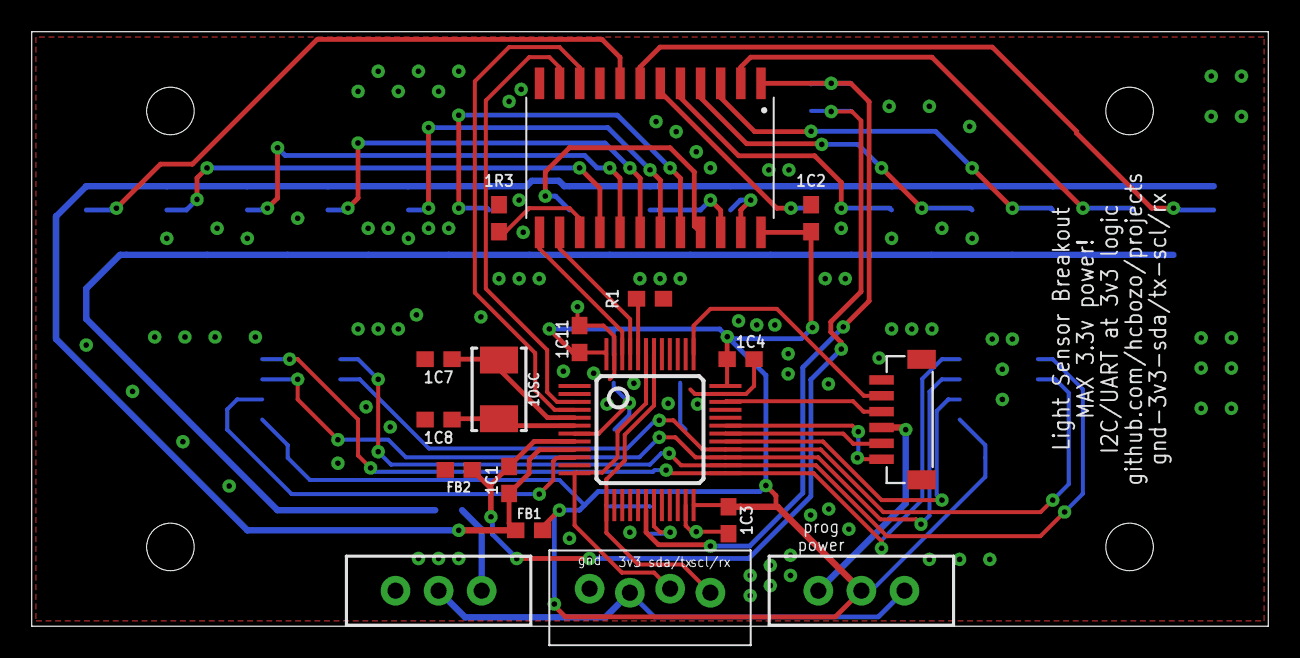
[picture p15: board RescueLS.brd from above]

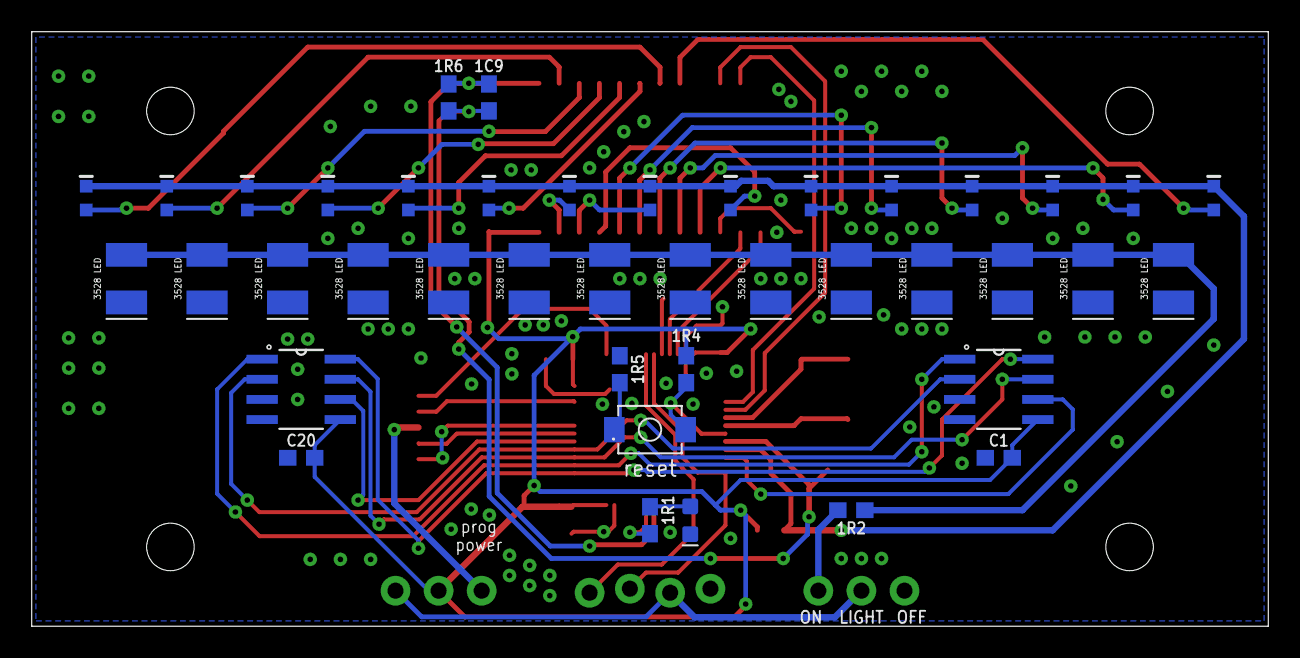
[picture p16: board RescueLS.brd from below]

Board: 2 copper layers, 78.0 x 37.5 mm, 59 parts (41 on the bottom side), 48 nets.

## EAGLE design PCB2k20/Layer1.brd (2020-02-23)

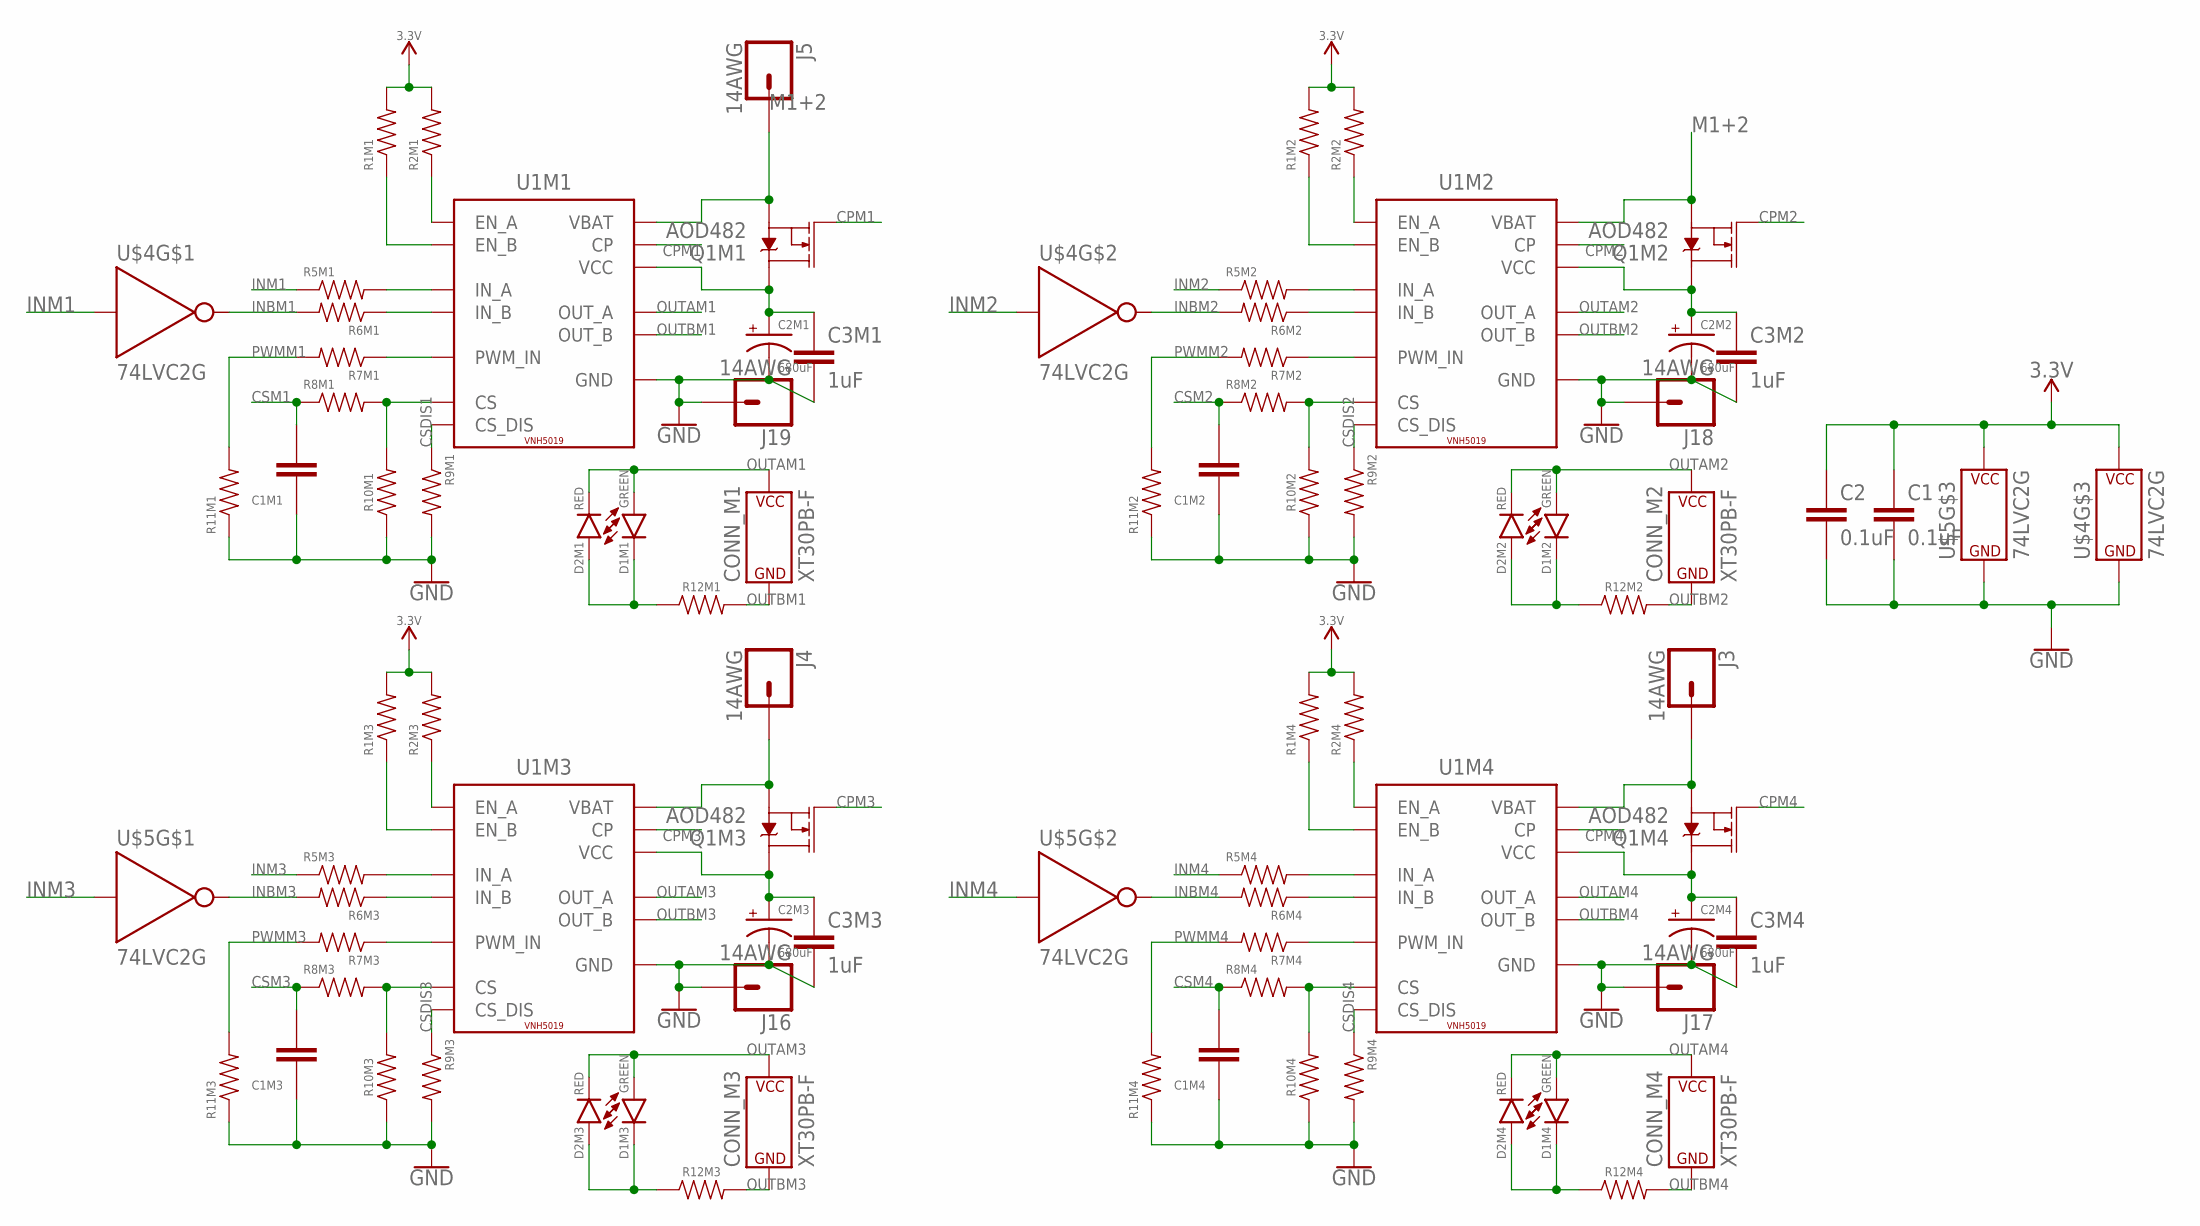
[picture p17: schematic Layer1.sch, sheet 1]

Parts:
C1, C2: 0.1uF; C0603
C1M1, C1M2, C1M3, C1M4: 33nF; C0603
C2M1, C2M2, C2M3, C2M4: 680uF; E3,5-8
C3M1, C3M2, C3M3, C3M4: 1uF; C0603
CONN_M1, CONN_M2, CONN_M3, CONN_M4: XT30PB-F
D1M1, D1M2, D1M3, D1M4: GREEN; LED-0603
D2M1, D2M2, D2M3, D2M4: RED; LED-0603
J3, J4, J5, J16, J17, J18, J19: 14AWG
Q1M1, Q1M2, Q1M3, Q1M4: AOD482; DPAK
R1M1, R1M2, R1M3, R1M4, R2M1, R2M2, R2M3, R2M4: 3.24k; R0603
R5M1, R5M2, R5M3, R5M4, R6M1, R6M2, R6M3, R6M4, R7M1, R7M2, R7M3, R7M4, R10M1, R10M2, R10M3, R10M4: 1k; R0603
R8M1, R8M2, R8M3, R8M4, R9M1, R9M2, R9M3, R9M4, R11M1, R11M2, R11M3, R11M4: 10k; R0603
R12M1, R12M2, R12M3, R12M4: 4.7k; R0603
U1M1, U1M2, U1M3, U1M4: VNH5019; POWERSO-30
U$4, U$5: 74LVC2G; SOT23-6

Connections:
3.3V: C1.1, C2.1, R1M1.2, R1M2.2, R1M3.2, R1M4.2, R2M1.2, R2M2.2, R2M3.2, R2M4.2, U$4.5 (P$V+), U$5.5 (P$V+); also elsewhere on the board
CPM1: Q1M1.1 (G), U1M1.P11 (CP)
CPM2: Q1M2.1 (G), U1M2.P11 (CP)
CPM3: Q1M3.1 (G), U1M3.P11 (CP)
CPM4: Q1M4.1 (G), U1M4.P11 (CP)
CSDIS1: R9M1.1, U1M1.P6 (CS_DIS)
CSDIS2: R9M2.1, U1M2.P6 (CS_DIS)
CSDIS3: R9M3.1, U1M3.P6 (CS_DIS)
CSDIS4: R9M4.1, U1M4.P6 (CS_DIS)
CSM1: C1M1.2, R8M1.1; also elsewhere on the board
CSM2: C1M2.2, R8M2.1; also elsewhere on the board
CSM3: C1M3.2, R8M3.1; also elsewhere on the board
CSM4: C1M4.2, R8M4.1; also elsewhere on the board
GND: C1.2, C1M1.1, C1M2.1, C1M3.1, C1M4.1, C2.2, C2M1.-, C2M2.-, C2M3.-, C2M4.-, C3M1.2, C3M2.2, C3M3.2, C3M4.2, J16.P$1, J17.P$1, J18.P$1, J19.P$1, R9M1.2, R9M2.2, R9M3.2, R9M4.2, R10M1.1, R10M2.1, R10M3.1, R10M4.1, R11M1.1, R11M2.1, R11M3.1, R11M4.1, U1M1.P18 (GND), U1M1.P19 (GND), U1M1.P20 (GND), U1M1.P26 (GND), U1M1.P27 (GND), U1M1.P28 (GND), U1M2.P18 (GND), U1M2.P19 (GND), U1M2.P20 (GND), U1M2.P26 (GND), U1M2.P27 (GND), U1M2.P28 (GND), U1M3.P18 (GND), U1M3.P19 (GND), U1M3.P20 (GND), U1M3.P26 (GND), U1M3.P27 (GND), U1M3.P28 (GND), U1M4.P18 (GND), U1M4.P19 (GND), U1M4.P20 (GND), U1M4.P26 (GND), U1M4.P27 (GND), U1M4.P28 (GND), U$4.2 (P$V-), U$5.2 (P$V-); also elsewhere on the board
INBM1: R6M1.2, U$4.6 (Y)
INBM2: R6M2.2, U$4.4 (Y)
INBM3: R6M3.2, U$5.6 (Y)
INBM4: R6M4.2, U$5.4 (Y)
INM1: R5M1.1, U$4.1 (A); also elsewhere on the board
INM2: R5M2.1, U$4.3 (A); also elsewhere on the board
INM3: R5M3.1, U$5.1 (A); also elsewhere on the board
INM4: R5M4.1, U$5.3 (A); also elsewhere on the board
M1+2: J5.P$1, Q1M1.3 (S), Q1M2.3 (S), U1M1.P12 (VBAT), U1M2.P12 (VBAT)
unnamed: J3.P$1, Q1M4.3 (S), U1M4.P12 (VBAT)
unnamed: J4.P$1, Q1M3.3 (S), U1M3.P12 (VBAT)
unnamed: C2M1.+, C3M1.1, Q1M1.4 (D), U1M1.P3 (VCC), U1M1.P13 (VCC), U1M1.P23 (VCC), U1M1.SLUG1 (VCC)
unnamed: R2M1.1, U1M1.P5 (EN_A)
unnamed: R5M1.2, U1M1.P4 (IN_A)
unnamed: R1M1.1, U1M1.P9 (EN_B)
unnamed: R6M1.1, U1M1.P10 (IN_B)
unnamed: R8M1.2, R10M1.2, U1M1.P8 (CS)
unnamed: R7M1.1, U1M1.P7 (PWM_IN)
unnamed: D1M2.C, D2M2.A, R12M2.1
unnamed: C2M2.+, C3M2.1, Q1M2.4 (D), U1M2.P3 (VCC), U1M2.P13 (VCC), U1M2.P23 (VCC), U1M2.SLUG1 (VCC)
unnamed: R2M2.1, U1M2.P5 (EN_A)
unnamed: R5M2.2, U1M2.P4 (IN_A)
unnamed: R1M2.1, U1M2.P9 (EN_B)
unnamed: R6M2.1, U1M2.P10 (IN_B)
unnamed: R8M2.2, R10M2.2, U1M2.P8 (CS)
unnamed: R7M2.1, U1M2.P7 (PWM_IN)
unnamed: D1M3.C, D2M3.A, R12M3.1
unnamed: C2M3.+, C3M3.1, Q1M3.4 (D), U1M3.P3 (VCC), U1M3.P13 (VCC), U1M3.P23 (VCC), U1M3.SLUG1 (VCC)
unnamed: R2M3.1, U1M3.P5 (EN_A)
unnamed: R5M3.2, U1M3.P4 (IN_A)
unnamed: R1M3.1, U1M3.P9 (EN_B)
unnamed: R6M3.1, U1M3.P10 (IN_B)
unnamed: R8M3.2, R10M3.2, U1M3.P8 (CS)
unnamed: R7M3.1, U1M3.P7 (PWM_IN)
unnamed: D1M4.C, D2M4.A, R12M4.1
unnamed: C2M4.+, C3M4.1, Q1M4.4 (D), U1M4.P3 (VCC), U1M4.P13 (VCC), U1M4.P23 (VCC), U1M4.SLUG1 (VCC)
unnamed: R2M4.1, U1M4.P5 (EN_A)
unnamed: R5M4.2, U1M4.P4 (IN_A)
unnamed: R1M4.1, U1M4.P9 (EN_B)
unnamed: R6M4.1, U1M4.P10 (IN_B)
unnamed: R8M4.2, R10M4.2, U1M4.P8 (CS)
unnamed: R7M4.1, U1M4.P7 (PWM_IN)
unnamed: D1M1.C, D2M1.A, R12M1.1
OUTAM1: CONN_M1.+ (P$V+), D1M1.A, D2M1.C, U1M1.P1 (OUT_A), U1M1.P25 (OUT_A), U1M1.P30 (OUT_A), U1M1.SLUG2 (OUT_A)
OUTAM2: CONN_M2.+ (P$V+), D1M2.A, D2M2.C, U1M2.P1 (OUT_A), U1M2.P25 (OUT_A), U1M2.P30 (OUT_A), U1M2.SLUG2 (OUT_A)
OUTAM3: CONN_M3.+ (P$V+), D1M3.A, D2M3.C, U1M3.P1 (OUT_A), U1M3.P25 (OUT_A), U1M3.P30 (OUT_A), U1M3.SLUG2 (OUT_A)
OUTAM4: CONN_M4.+ (P$V+), D1M4.A, D2M4.C, U1M4.P1 (OUT_A), U1M4.P25 (OUT_A), U1M4.P30 (OUT_A), U1M4.SLUG2 (OUT_A)
OUTBM1: CONN_M1.- (P$V-), R12M1.2, U1M1.P15 (OUT_B), U1M1.P16 (OUT_B), U1M1.P21 (OUT_B), U1M1.SLUG3 (OUT_B)
OUTBM2: CONN_M2.- (P$V-), R12M2.2, U1M2.P15 (OUT_B), U1M2.P16 (OUT_B), U1M2.P21 (OUT_B), U1M2.SLUG3 (OUT_B)
OUTBM3: CONN_M3.- (P$V-), R12M3.2, U1M3.P15 (OUT_B), U1M3.P16 (OUT_B), U1M3.P21 (OUT_B), U1M3.SLUG3 (OUT_B)
OUTBM4: CONN_M4.- (P$V-), R12M4.2, U1M4.P15 (OUT_B), U1M4.P16 (OUT_B), U1M4.P21 (OUT_B), U1M4.SLUG3 (OUT_B)
PWMM1: R7M1.2, R11M1.2; also elsewhere on the board
PWMM2: R7M2.2, R11M2.2; also elsewhere on the board
PWMM3: R7M3.2, R11M3.2; also elsewhere on the board
PWMM4: R7M4.2, R11M4.2; also elsewhere on the board

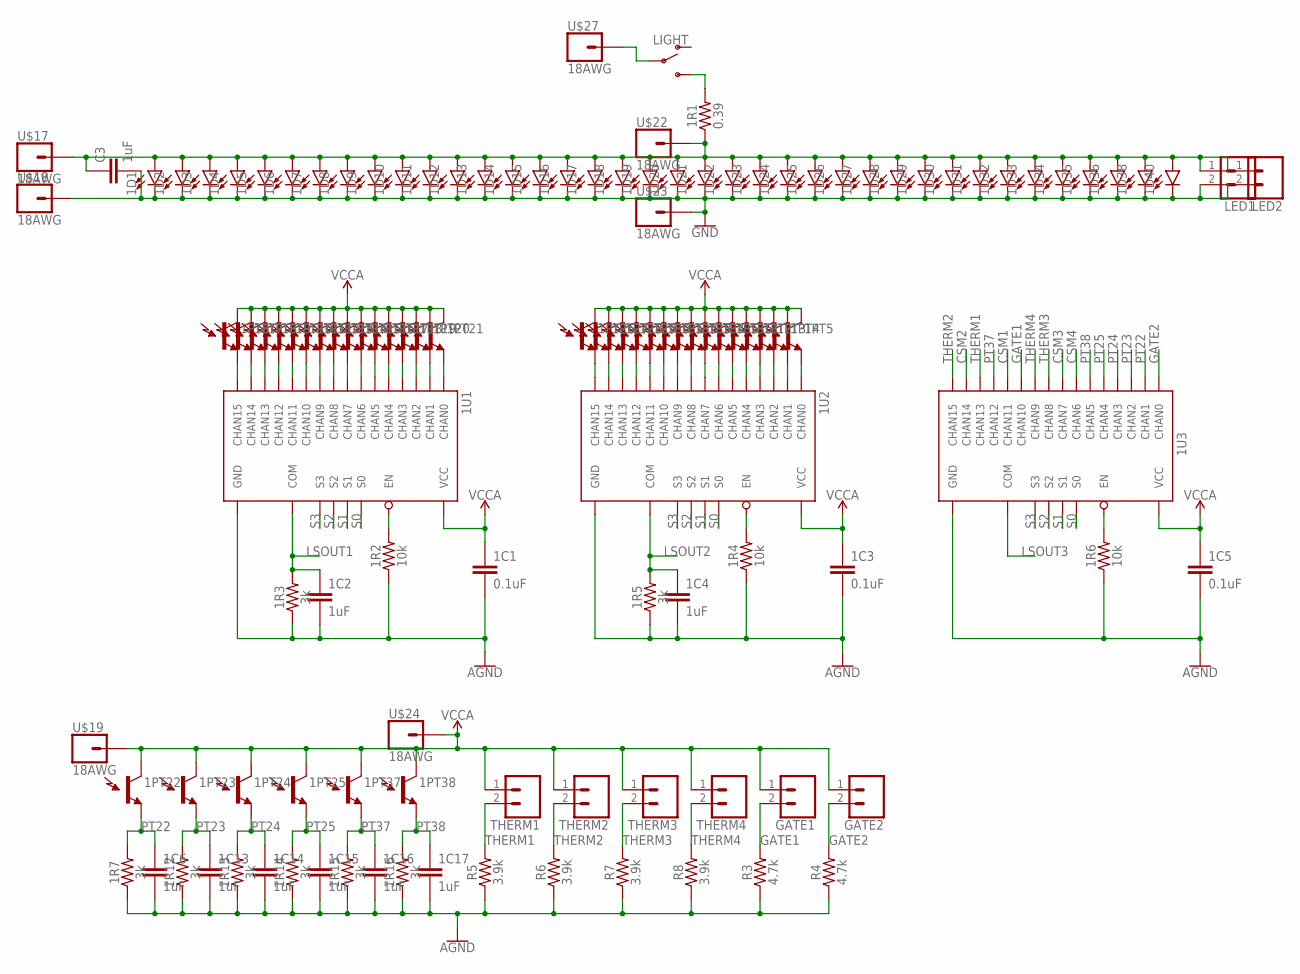
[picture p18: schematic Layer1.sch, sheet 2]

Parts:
1C1, 1C3, 1C5: 0.1uF; C0603
1C2, 1C4, 1C6, 1C13, 1C14, 1C15, 1C16, 1C17: 1uF; C0603
1D1, 1D2, 1D3, 1D4, 1D5, 1D6, 1D7, 1D8, 1D9, 1D10, 1D11, 1D12, 1D13, 1D14, 1D15, 1D16, 1D17, 1D18, 1D19, 1D20, 1D21, 1D22, 1D23, 1D24, 1D25, 1D26, 1D27, 1D28, 1D29, 1D30, 1D31, 1D32, 1D33, 1D34, 1D35, 1D36, 1D38, 1D40: 3528LED; 3528
1PT1, 1PT2, 1PT3, 1PT4, 1PT5, 1PT6, 1PT7, 1PT8, 1PT9, 1PT10, 1PT11, 1PT12, 1PT13, 1PT14, 1PT15, 1PT16, 1PT17, 1PT18, 1PT19, 1PT20, 1PT21, 1PT22, 1PT23, 1PT24, 1PT25, 1PT26, 1PT27, 1PT28, 1PT29, 1PT30, 1PT31, 1PT32, 1PT33, 1PT34, 1PT35, 1PT36, 1PT37, 1PT38: LIGHT_SENSORALS; ALS-PT19
1R1: 0.39; R0603
1R2, 1R4, 1R6: 10k; R0603
1R3, 1R5, 1R7, 1R12, 1R13, 1R14, 1R15, 1R16: 3k; R0603
1U1, 1U2, 1U3: CD74HC4067SSOP-24; SSOP24
C3: 1uF; C0603
GATE1, GATE2: CONN_021X02_NO_SILK; 1X02_NO_SILK
LED1, LED2: CONN_021X02_NO_SILK; 1X02_NO_SILK
LIGHT: SWITCH-SPDT-PTH-11.6X4.0MM-LOCK; SWITCH_SPDT_PTH_11.6X4.0MM_LOCK
R3, R4: 4.7k; R0603
R5, R6, R7, R8: 3.9k; R0603
THERM1, THERM2, THERM3, THERM4: CONN_021X02_NO_SILK; 1X02_NO_SILK
U$17, U$18, U$19, U$22, U$23, U$24, U$27: 18AWG

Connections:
AGND: 1C1.2, 1C2.2, 1C3.2, 1C4.2, 1C5.2, 1C6.2, 1C13.2, 1C14.2, 1C15.2, 1C16.2, 1C17.2, 1R2.1, 1R3.1, 1R4.1, 1R5.1, 1R6.1, 1R7.1, 1R12.1, 1R13.1, 1R14.1, 1R15.1, 1R16.1, 1U1.12 (GND), 1U2.12 (GND), 1U3.12 (GND), R3.1, R4.1, R5.1, R6.1, R7.1, R8.1; also elsewhere on the board
CSM1: 1U3.20 (CHAN11); also elsewhere on the board
CSM2: 1U3.17 (CHAN14); also elsewhere on the board
CSM3: 1U3.2 (CHAN7); also elsewhere on the board
CSM4: 1U3.3 (CHAN6); also elsewhere on the board
GATE1: 1U3.21 (CHAN10), GATE1.2, R3.2
GATE2: 1U3.9 (CHAN0), GATE2.2, R4.2
GND: 1D1.C, 1D2.C, 1D3.C, 1D4.C, 1D5.C, 1D6.C, 1D7.C, 1D8.C, 1D9.C, 1D10.C, 1D11.C, 1D12.C, 1D13.C, 1D14.C, 1D15.C, 1D16.C, 1D17.C, 1D18.C, 1D19.C, 1D20.C, 1D21.C, 1D22.C, 1D23.C, 1D24.C, 1D25.C, 1D26.C, 1D27.C, 1D28.C, 1D29.C, 1D30.C, 1D31.C, 1D32.C, 1D33.C, 1D34.C, 1D35.C, 1D36.C, 1D38.C, 1D40.C, C3.2, LED1.2, LED2.2, U$18.P$1, U$23.P$1; also elsewhere on the board
LSOUT1: 1C2.1, 1R3.2, 1U1.1 (COM); also elsewhere on the board
LSOUT2: 1C4.1, 1R5.2, 1U2.1 (COM); also elsewhere on the board
LSOUT3: 1U3.1 (COM); also elsewhere on the board
unnamed: 1D1.A, 1D2.A, 1D3.A, 1D4.A, 1D5.A, 1D6.A, 1D7.A, 1D8.A, 1D9.A, 1D10.A, 1D11.A, 1D12.A, 1D13.A, 1D14.A, 1D15.A, 1D16.A, 1D17.A, 1D18.A, 1D19.A, 1D20.A, 1D21.A, 1D22.A, 1D23.A, 1D24.A, 1D25.A, 1D26.A, 1D27.A, 1D28.A, 1D29.A, 1D30.A, 1D31.A, 1D32.A, 1D33.A, 1D34.A, 1D35.A, 1D36.A, 1D38.A, 1D40.A, 1R1.1, C3.1, LED1.1, LED2.1, U$17.P$1, U$22.P$1
unnamed: 1PT26.E (E1), 1U2.16 (CHAN15)
unnamed: 1R1.2, LIGHT.3 (S)
unnamed: 1PT27.E (E1), 1U2.17 (CHAN14)
unnamed: 1PT28.E (E1), 1U2.18 (CHAN13)
unnamed: 1PT29.E (E1), 1U2.19 (CHAN12)
unnamed: 1PT30.E (E1), 1U2.20 (CHAN11)
unnamed: 1PT31.E (E1), 1U2.21 (CHAN10)
unnamed: 1PT32.E (E1), 1U2.22 (CHAN9)
unnamed: 1PT33.E (E1), 1U2.23 (CHAN8)
unnamed: 1PT34.E (E1), 1U2.2 (CHAN7)
unnamed: 1PT35.E (E1), 1U2.3 (CHAN6)
unnamed: 1PT36.E (E1), 1U2.4 (CHAN5)
unnamed: 1PT1.E (E1), 1U2.5 (CHAN4)
unnamed: 1PT2.E (E1), 1U2.6 (CHAN3)
unnamed: 1PT3.E (E1), 1U2.7 (CHAN2)
unnamed: 1PT4.E (E1), 1U2.8 (CHAN1)
unnamed: 1PT5.E (E1), 1U2.9 (CHAN0)
unnamed: 1PT6.E (E1), 1U1.16 (CHAN15)
unnamed: 1R2.2, 1U1.15 (EN)
unnamed: 1PT7.E (E1), 1U1.17 (CHAN14)
unnamed: 1PT8.E (E1), 1U1.18 (CHAN13)
unnamed: 1PT9.E (E1), 1U1.19 (CHAN12)
unnamed: 1PT10.E (E1), 1U1.20 (CHAN11)
unnamed: 1PT11.E (E1), 1U1.21 (CHAN10)
unnamed: 1PT12.E (E1), 1U1.22 (CHAN9)
unnamed: 1PT13.E (E1), 1U1.23 (CHAN8)
unnamed: 1PT14.E (E1), 1U1.2 (CHAN7)
unnamed: 1PT15.E (E1), 1U1.3 (CHAN6)
unnamed: 1PT16.E (E1), 1U1.4 (CHAN5)
unnamed: 1PT17.E (E1), 1U1.5 (CHAN4)
unnamed: 1PT18.E (E1), 1U1.6 (CHAN3)
unnamed: 1PT19.E (E1), 1U1.7 (CHAN2)
unnamed: 1PT20.E (E1), 1U1.8 (CHAN1)
unnamed: 1PT21.E (E1), 1U1.9 (CHAN0)
unnamed: LIGHT.2, U$27.P$1
unnamed: 1R4.2, 1U2.15 (EN)
unnamed: 1R6.2, 1U3.15 (EN)
PT22: 1C6.1, 1PT22.E (E1), 1R7.2, 1U3.8 (CHAN1)
PT23: 1C13.1, 1PT23.E (E1), 1R12.2, 1U3.7 (CHAN2)
PT24: 1C14.1, 1PT24.E (E1), 1R13.2, 1U3.6 (CHAN3)
PT25: 1C15.1, 1PT25.E (E1), 1R14.2, 1U3.5 (CHAN4)
PT37: 1C16.1, 1PT37.E (E1), 1R15.2, 1U3.19 (CHAN12)
PT38: 1C17.1, 1PT38.E (E1), 1R16.2, 1U3.4 (CHAN5)
S0: 1U1.10 (S0), 1U2.10 (S0), 1U3.10 (S0); also elsewhere on the board
S1: 1U1.11 (S1), 1U2.11 (S1), 1U3.11 (S1); also elsewhere on the board
S2: 1U1.14 (S2), 1U2.14 (S2), 1U3.14 (S2); also elsewhere on the board
S3: 1U1.13 (S3), 1U2.13 (S3), 1U3.13 (S3); also elsewhere on the board
THERM1: 1U3.18 (CHAN13), R5.2, THERM1.2
THERM2: 1U3.16 (CHAN15), R6.2, THERM2.2
THERM3: 1U3.23 (CHAN8), R7.2, THERM3.2
THERM4: 1U3.22 (CHAN9), R8.2, THERM4.2
VCCA: 1C1.1, 1C3.1, 1C5.1, 1PT1.C (C1), 1PT2.C (C1), 1PT3.C (C1), 1PT4.C (C1), 1PT5.C (C1), 1PT6.C (C1), 1PT7.C (C1), 1PT8.C (C1), 1PT9.C (C1), 1PT10.C (C1), 1PT11.C (C1), 1PT12.C (C1), 1PT13.C (C1), 1PT14.C (C1), 1PT15.C (C1), 1PT16.C (C1), 1PT17.C (C1), 1PT18.C (C1), 1PT19.C (C1), 1PT20.C (C1), 1PT21.C (C1), 1PT22.C (C1), 1PT23.C (C1), 1PT24.C (C1), 1PT25.C (C1), 1PT26.C (C1), 1PT27.C (C1), 1PT28.C (C1), 1PT29.C (C1), 1PT30.C (C1), 1PT31.C (C1), 1PT32.C (C1), 1PT33.C (C1), 1PT34.C (C1), 1PT35.C (C1), 1PT36.C (C1), 1PT37.C (C1), 1PT38.C (C1), 1U1.24 (VCC), 1U2.24 (VCC), 1U3.24 (VCC), GATE1.1, GATE2.1, THERM1.1, THERM2.1, THERM3.1, THERM4.1, U$19.P$1, U$24.P$1; also elsewhere on the board

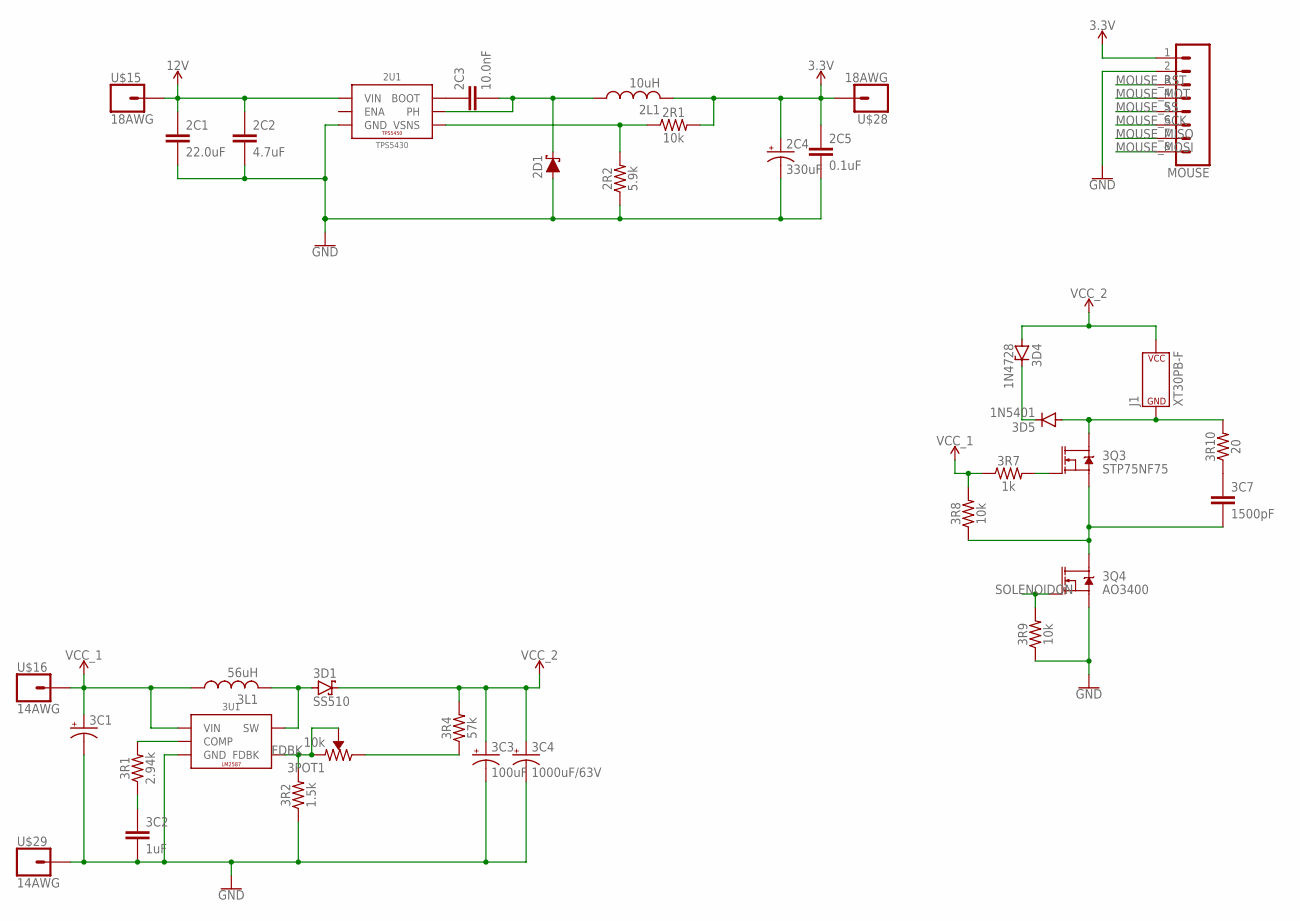
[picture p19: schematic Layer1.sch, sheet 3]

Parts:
2C1: 22.0uF; C1210
2C2: 4.7uF; C0603
2C3: 10.0nF; C0603
2C4: 330uF; D/7343-31R
2C5: 0.1uF; C0603
2D1: SS54; SMA-DIODE
2L1: 10uH; SWPA8040
2R1, 3R8, 3R9: 10k; R0603
2R2: 5.9k; R0603
2U1: TPS5430; POWERPAD-SOIC-8
3C1: 100uF; PANASONIC_D
3C2: 1uF; C0603
3C3: 100uF; NIC_10X10.5_CAP
3C4: 1000uF/63V; 1000UF-CAP
3C7: 1500pF; C0603
3D1: SS510; SMB
3D4: 1N4728; DO41Z10
3D5: 1N5401; DO201-15
3L1: 56uH; CDRH127
3POT1: 10k; 3296-TRIMPOT
3Q3: STP75NF75; TO220V
3Q4: AO3400; SOT23-3
3R1: 2.94k; R0603
3R2: 1.5k; R0603
3R4: 57k; R0603
3R7: 1k; R0603
3R10: 20; R0603
3U1: LM2587; TO-263
J1: XT30PB-F
MOUSE: CONN_08LOCK; 1X08_LOCK
U$15, U$28: 18AWG
U$16, U$29: 14AWG

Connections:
3.3V: 2C4.+, 2C5.1, 2L1.P2 (2), 2R1.2, MOUSE.1, U$28.P$1; also elsewhere on the board
12V: 2C1.1, 2C2.1, 2U1.7 (VIN), U$15.P$1
FDBK: 3POT1.1 (CCW), 3POT1.2 (WIPER), 3R2.2, 3U1.P2 (FDBK)
GND: 2C1.2, 2C2.2, 2C4.-, 2C5.2, 2D1.A, 2R2.1, 2U1.6 (GND), 2U1.9 (GND), 2U1.P$1 (GND), 2U1.P$2 (GND), 2U1.P$3 (GND), 2U1.P$4 (GND), 2U1.P$5 (GND), 2U1.P$6 (GND), 3C1.-, 3C2.2, 3C3.-, 3C4.-, 3Q4.2 (S), 3R2.1, 3R9.1, 3U1.P3 (GND), 3U1.P$1 (GND), 3U1.P$2 (GND), 3U1.P$3 (GND), 3U1.P$4 (GND), 3U1.P$5 (GND), 3U1.P$6 (GND), 3U1.P$7 (GND), 3U1.P$8 (GND), 3U1.P$9 (GND), 3U1.P$10 (GND), 3U1.P$11 (GND), 3U1.P$12 (GND), 3U1.P$13 (GND), 3U1.P$14 (GND), 3U1.P$15 (GND), 3U1.P$16 (GND), 3U1.P$17 (GND), 3U1.P$18 (GND), 3U1.P$19 (GND), 3U1.P$20 (GND), 3U1.TAB (GND), MOUSE.2, U$29.P$1; also elsewhere on the board
MOUSE_MISO: MOUSE.7; also elsewhere on the board
MOUSE_MOSI: MOUSE.8; also elsewhere on the board
MOUSE_MOT: MOUSE.4; also elsewhere on the board
MOUSE_RST: MOUSE.3; also elsewhere on the board
MOUSE_SCK: MOUSE.6; also elsewhere on the board
MOUSE_SS: MOUSE.5; also elsewhere on the board
unnamed: 3POT1.3 (CW), 3R4.1
unnamed: 3D1.A, 3L1.2, 3U1.P4 (SW)
unnamed: 3R1.2, 3U1.P1 (COMP)
unnamed: 3C2.1, 3R1.1
unnamed: 3C7.2, 3Q3.3 (S), 3Q4.3 (D), 3R8.1
unnamed: 3Q3.1 (G), 3R7.2
unnamed: 3D4.C, 3D5.C
unnamed: 2C3.2, 2D1.C, 2L1.P1 (1), 2U1.8 (PH)
unnamed: 2R1.1, 2R2.2, 2U1.4 (VSNS)
unnamed: 2C3.1, 2U1.1 (BOOT)
unnamed: 3C7.1, 3R10.1
SOLENOIDGND: 3D5.A, 3Q3.2 (D), 3R10.2, J1.- (P$V-)
SOLENOIDON: 3Q4.1 (G), 3R9.2; also elsewhere on the board
VCC_1: 3C1.+, 3L1.1, 3R7.1, 3R8.2, 3U1.P5 (VIN), U$16.P$1
VCC_2: 3C3.+, 3C4.+, 3D1.C, 3D4.A, 3R4.2, J1.+ (P$V+)

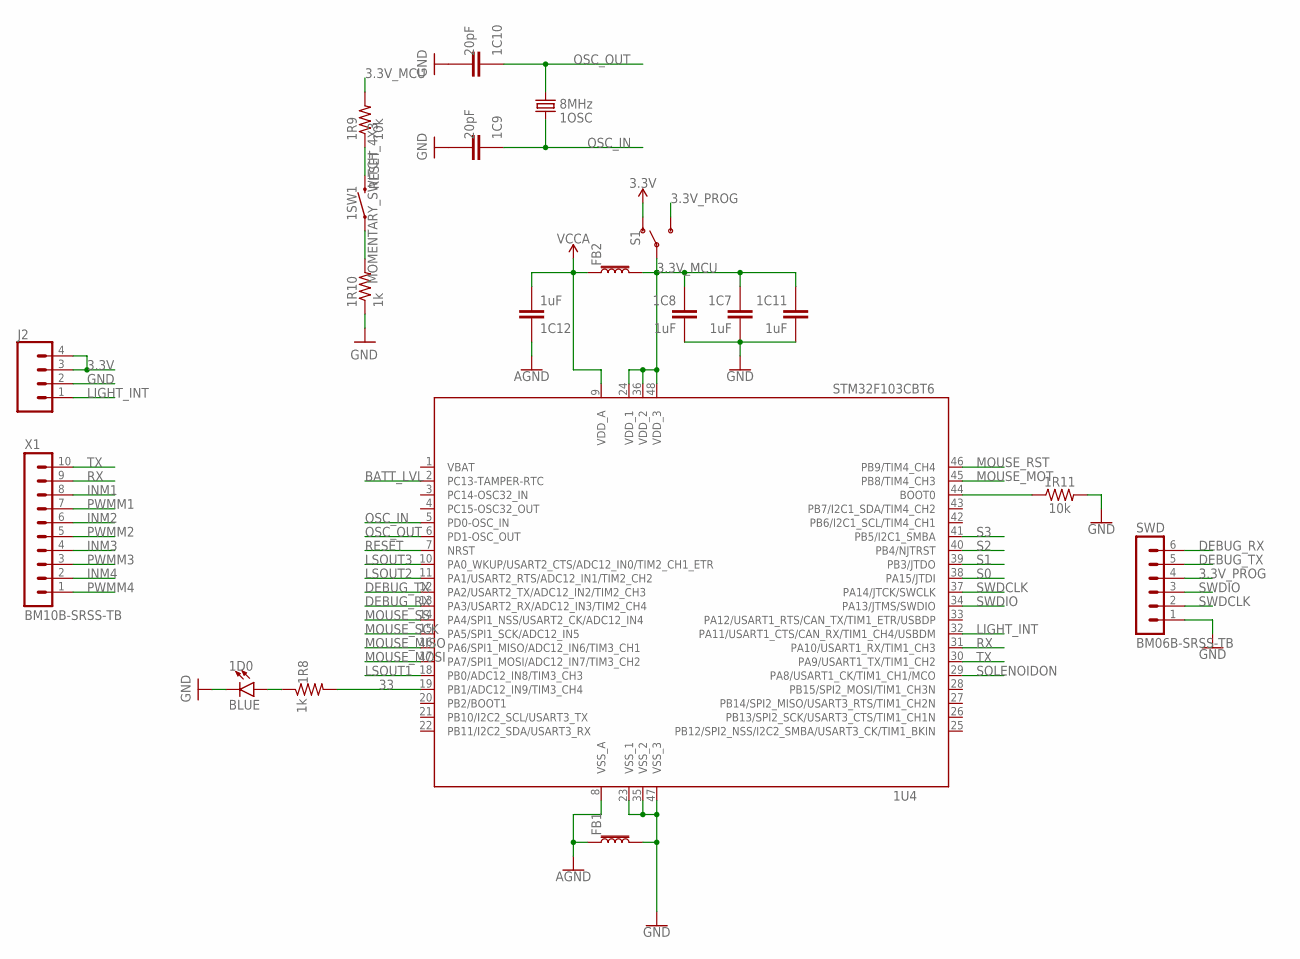
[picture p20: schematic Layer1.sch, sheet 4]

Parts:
1C7, 1C8, 1C11, 1C12: 1uF; C0603
1C9, 1C10: 20pF; C0603
1D0: BLUE; LED-0603
1OSC: 8MHz; CRYSTAL-SMD-5X3.2-2PAD
1R8, 1R10: 1k; R0603
1R9, 1R11: 10k; R0603
1SW1: MOMENTARY_SWITCH_4X3
1U4: STM32F103CBT6; LQFP48
FB1, FB2: 30Ω/1.8A; 0603
J2: CONN_04; 1X04
S1: SWITCH-SPDT-PTH-11.6X4.0MM-LOCK; SWITCH_SPDT_PTH_11.6X4.0MM_LOCK
SWD: BM06B-SRSS-TB
X1: BM10B-SRSS-TB

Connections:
3.3V: J2.3, J2.4, S1.1 (O); also elsewhere on the board
3.3V_MCU: 1C7.1, 1C8.1, 1C11.1, 1R9.2, 1U4.24 (VDD_1), 1U4.36 (VDD_2), 1U4.48 (VDD_3), FB2.2, S1.2
3.3V_PROG: S1.3 (S), SWD.4
33: 1R8.2, 1U4.19 (PB1/ADC12_IN9/TIM3_CH4)
AGND: 1C12.1, 1U4.8 (VSS_A), FB1.1; also elsewhere on the board
BATT_LVL: 1U4.2 (PC13-TAMPER-RTC); also elsewhere on the board
DEBUG_RX: 1U4.13 (PA3/USART2_RX/ADC12_IN3/TIM2_CH4), SWD.6
DEBUG_TX: 1U4.12 (PA2/USART2_TX/ADC12_IN2/TIM2_CH3), SWD.5
GND: 1C7.2, 1C8.2, 1C9.2, 1C10.2, 1C11.2, 1D0.C, 1R10.1, 1R11.2, 1U4.23 (VSS_1), 1U4.35 (VSS_2), 1U4.47 (VSS_3), FB1.2, J2.2, SWD.1; also elsewhere on the board
INM1: X1.8; also elsewhere on the board
INM2: X1.6; also elsewhere on the board
INM3: X1.4; also elsewhere on the board
INM4: X1.2; also elsewhere on the board
LIGHT_INT: 1U4.32 (PA11/USART1_CTS/CAN_RX/TIM1_CH4/USBDM), J2.1
LSOUT1: 1U4.18 (PB0/ADC12_IN8/TIM3_CH3); also elsewhere on the board
LSOUT2: 1U4.11 (PA1/USART2_RTS/ADC12_IN1/TIM2_CH2); also elsewhere on the board
LSOUT3: 1U4.10 (PA0_WKUP/USART2_CTS/ADC12_IN0/TIM2_CH1_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); also elsewhere on the board
MOUSE_MISO: 1U4.16 (PA6/SPI1_MISO/ADC12_IN6/TIM3_CH1); also elsewhere on the board
MOUSE_MOSI: 1U4.17 (PA7/SPI1_MOSI/ADC12_IN7/TIM3_CH2); also elsewhere on the board
MOUSE_MOT: 1U4.45 (PB8/TIM4_CH3); also elsewhere on the board
MOUSE_RST: 1U4.46 (PB9/TIM4_CH4); also elsewhere on the board
MOUSE_SCK: 1U4.15 (PA5/SPI1_SCK/ADC12_IN5); also elsewhere on the board
MOUSE_SS: 1U4.14 (PA4/SPI1_NSS/USART2_CK/ADC12_IN4); also elsewhere on the board
unnamed: 1R10.2, 1SW1.P$1 (1)
unnamed: 1D0.A, 1R8.1
unnamed: 1R11.1, 1U4.44 (BOOT0)
OSC_IN: 1C9.1, 1OSC.P$2 (2), 1U4.5 (PD0-OSC_IN)
OSC_OUT: 1C10.1, 1OSC.P$1 (1), 1U4.6 (PD1-OSC_OUT)
PWMM1: X1.7; also elsewhere on the board
PWMM2: X1.5; also elsewhere on the board
PWMM3: X1.3; also elsewhere on the board
PWMM4: X1.1; also elsewhere on the board
RESET: 1R9.1, 1SW1.P$2 (2), 1U4.7 (NRST)
RX: 1U4.31 (PA10/USART1_RX/TIM1_CH3), X1.9
S0: 1U4.38 (PA15/JTDI); also elsewhere on the board
S1: 1U4.39 (PB3/JTDO); also elsewhere on the board
S2: 1U4.40 (PB4/NJTRST); also elsewhere on the board
S3: 1U4.41 (PB5/I2C1_SMBA); also elsewhere on the board
SOLENOIDON: 1U4.29 (PA8/USART1_CK/TIM1_CH1/MCO); also elsewhere on the board
SWDCLK: 1U4.37 (PA14/JTCK/SWCLK), SWD.2
SWDIO: 1U4.34 (PA13/JTMS/SWDIO), SWD.3
TX: 1U4.30 (PA9/USART1_TX/TIM1_CH2), X1.10
VBAT: 1U4.1 (VBAT)
VCCA: 1C12.2, 1U4.9 (VDD_A), FB2.1; also elsewhere on the board

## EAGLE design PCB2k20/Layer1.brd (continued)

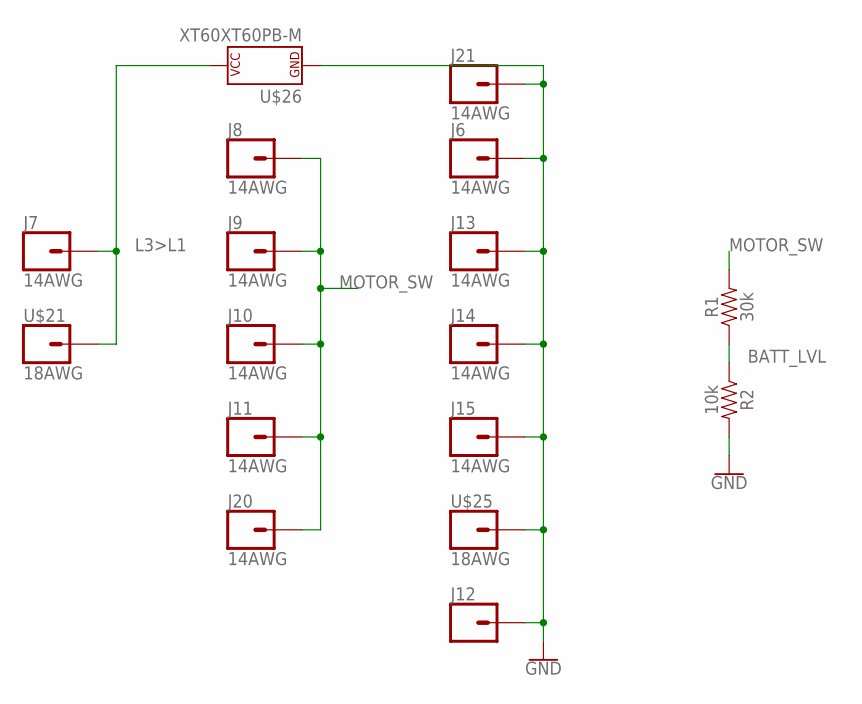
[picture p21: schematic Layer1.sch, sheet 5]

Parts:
J6, J7, J8, J9, J10, J11, J13, J14, J15, J20, J21: 14AWG
J12: CONN_01; 1X01
R1: 30k; R0603
R2: 10k; R0603
U$21, U$25: 18AWG
U$26: XT60XT60PB-M; XT60PB-M

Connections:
BATT_LVL: R1.1, R2.1; also elsewhere on the board
GND: J6.P$1, J12.1, J13.P$1, J14.P$1, J15.P$1, J21.P$1, R2.2, U$25.P$1, U$26.- (P$V-); also elsewhere on the board
L3>L1: J7.P$1, U$21.P$1, U$26.+ (P$V+)
MOTOR_SW: J8.P$1, J9.P$1, J10.P$1, J11.P$1, J20.P$1, R1.2

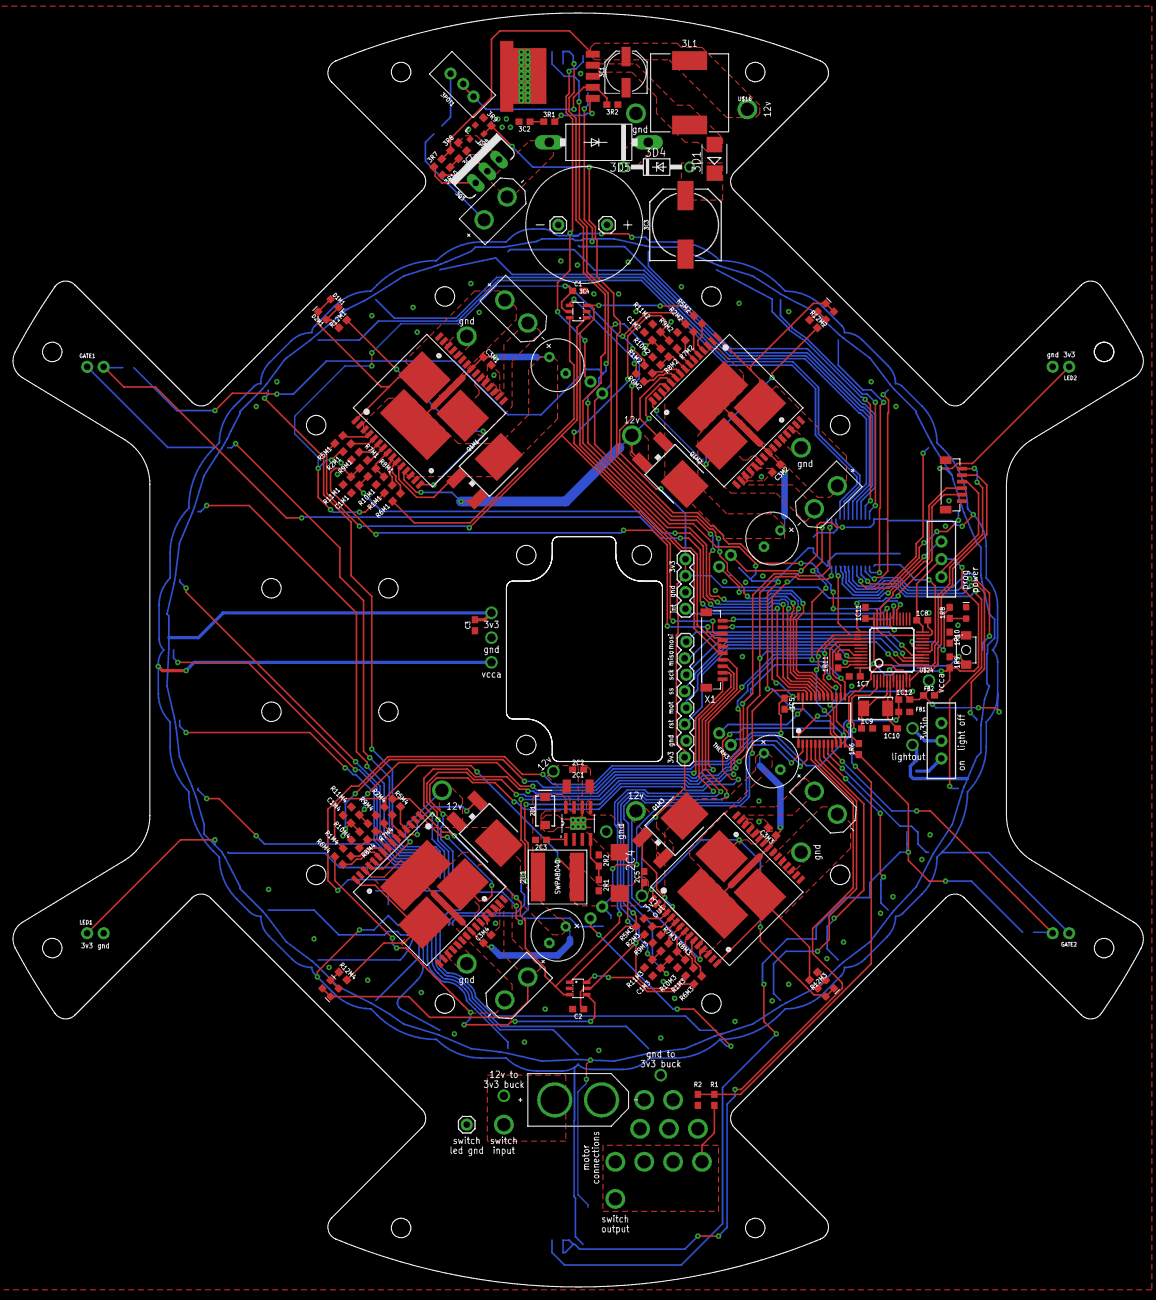
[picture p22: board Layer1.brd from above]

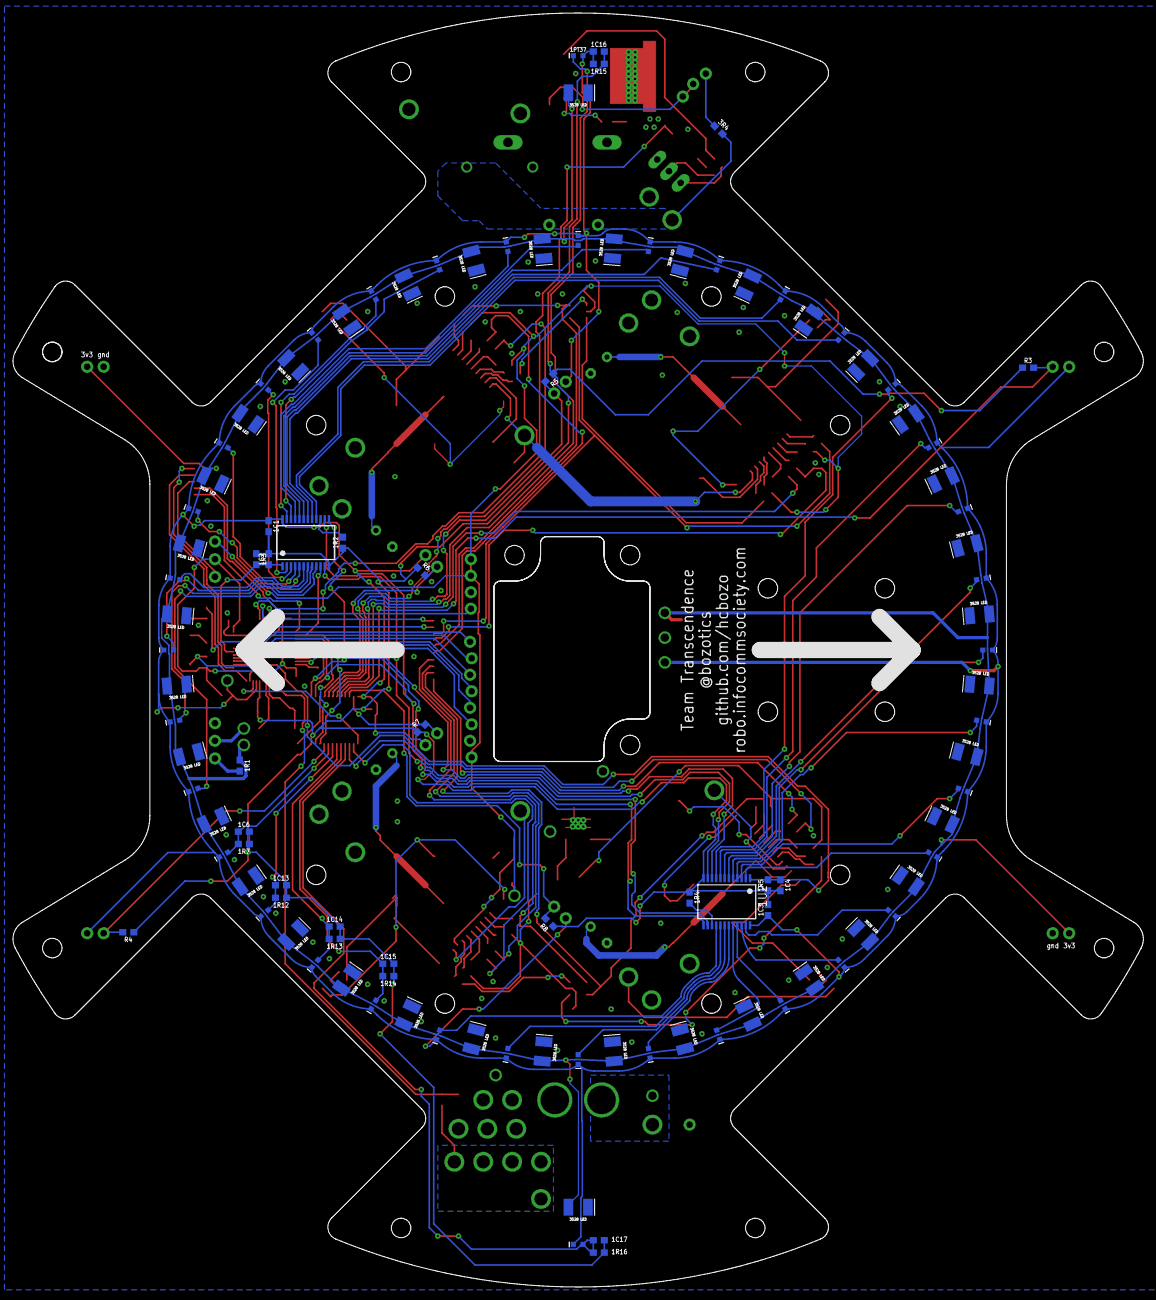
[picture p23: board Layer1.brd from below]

Board: 2 copper layers, 173.9 x 196.0 mm, 281 parts (106 on the bottom side), 170 nets.

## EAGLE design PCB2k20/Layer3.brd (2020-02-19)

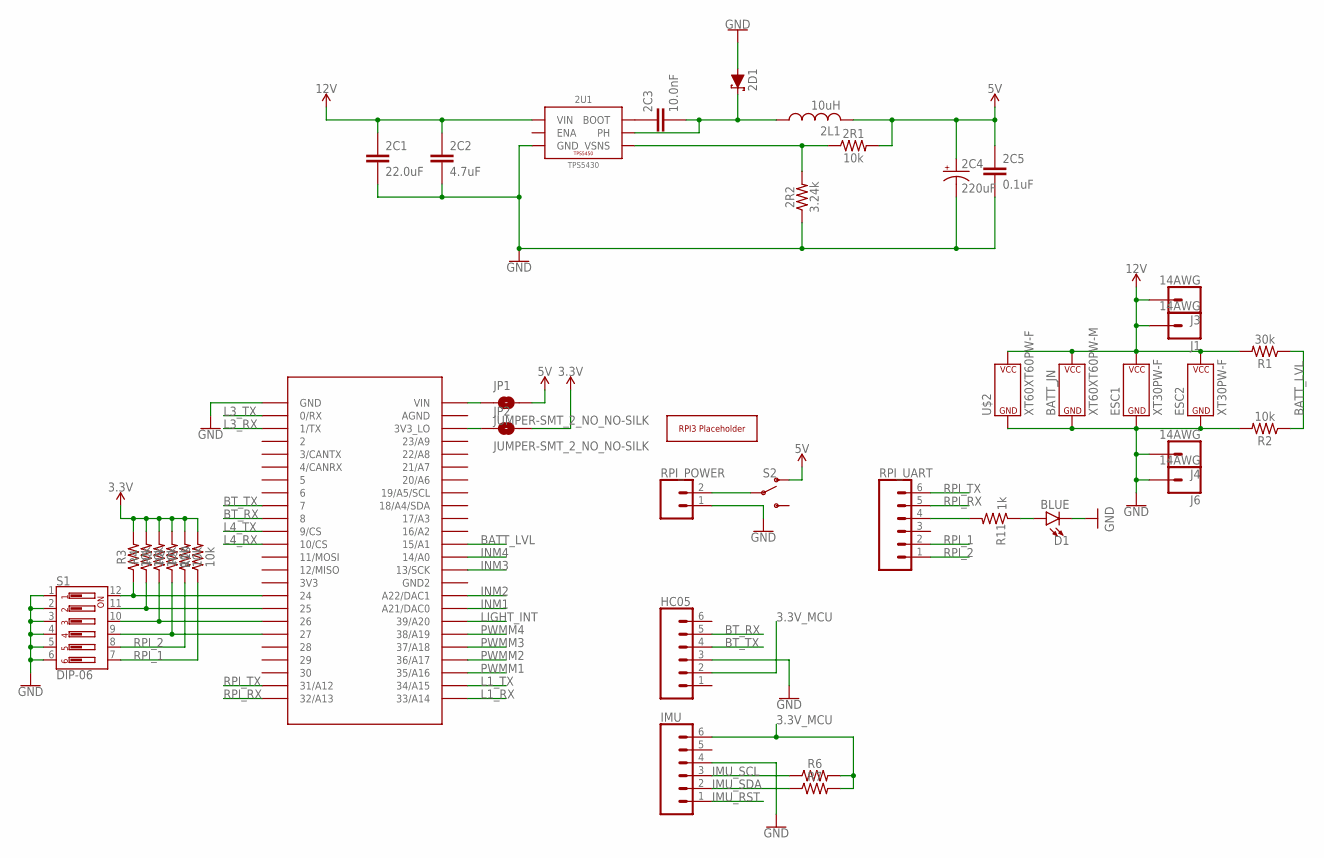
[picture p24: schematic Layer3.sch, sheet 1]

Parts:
2C1: 22.0uF; C1210
2C2: 4.7uF; C0603
2C3: 10.0nF; C0603
2C4: 220uF; D/7343-31R
2C5: 0.1uF; C0603
2D1: 3A/40V/500mV; SMA-DIODE
2L1: 10uH; SWPA8040
2R1: 10k; R0603
2R2: 3.24k; R0603
2U1: TPS5430; POWERPAD-SOIC-8
BATT_JN: XT60XT60PW-M; XT60PW-M
D1: BLUE; LED-0603
ESC1, ESC2: XT30PW-F
HC05: CONN_06RA_LOCK; MOLEX_1X6_RA_LOCK
IMU: CONN_06FEMALE_LOCK; 1X06_FEMALE_LOCK.010
J1, J3, J4, J6: 14AWG
JP1, JP2: JUMPER-SMT_2_NO_NO-SILK; SMT-JUMPER_2_NO_NO-SILK
PCB1: RPI3
R1: 30k; R0603
R2, R3, R4, R5, R8, R9, R10: 10k; R0603
R6, R7: RESISTOR0603; R0603
R11: 1k; R0603
RPI_POWER: CONN_02LOCK; 1X02_LOCK
RPI_UART: CONN_06LOCK; 1X06_LOCK
S1: DIP-06; DIPSWITCH-06-SMD
S2: SWITCH-SPDT-PTH-11.6X4.0MM-LOCK; SWITCH_SPDT_PTH_11.6X4.0MM_LOCK
U$1: TEENSY_3.5/3.6_NO_MIDDLE
U$2: XT60XT60PW-F; XT60PW-F

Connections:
3.3V: JP2.2, R3.2, R4.2, R5.2, R8.2, R9.2, R10.2; also elsewhere on the board
3.3V_MCU: HC05.2, IMU.6, R6.2, R7.2; also elsewhere on the board
5V: 2C4.+, 2C5.1, 2L1.P2 (2), 2R1.2, JP1.2, S2.1 (O); also elsewhere on the board
12V: 2C1.1, 2C2.1, 2U1.7 (VIN), BATT_JN.+ (P$V+), ESC1.+ (P$V+), ESC2.+ (P$V+), J1.P$1, J3.P$1, R1.2, U$2.+ (P$V+)
BATT_LVL: R1.1, R2.1, U$1.15/A1
BT_RX: HC05.5, U$1.8
BT_TX: HC05.4, U$1.7
GND: 2C1.2, 2C2.2, 2C4.-, 2C5.2, 2D1.A, 2R2.1, 2U1.6 (GND), 2U1.9 (GND), 2U1.P$1 (GND), 2U1.P$2 (GND), 2U1.P$3 (GND), 2U1.P$4 (GND), 2U1.P$5 (GND), 2U1.P$6 (GND), BATT_JN.- (P$V-), D1.C, ESC1.- (P$V-), ESC2.- (P$V-), HC05.3, IMU.4, J4.P$1, J6.P$1, R2.2, RPI_POWER.1, S1.1, S1.2, S1.3, S1.4, S1.5, S1.6, U$1.GND, U$2.- (P$V-); also elsewhere on the board
IMU_RST: IMU.1; also elsewhere on the board
IMU_SCL: IMU.3, R6.1; also elsewhere on the board
IMU_SDA: IMU.2, R7.1; also elsewhere on the board
INM1: U$1.A21/DAC0; also elsewhere on the board
INM2: U$1.A22/DAC1; also elsewhere on the board
INM3: U$1.13/SCK; also elsewhere on the board
INM4: U$1.14/A0; also elsewhere on the board
L1_RX: U$1.33/A14; also elsewhere on the board
L1_TX: U$1.34/A15; also elsewhere on the board
L3_RX: U$1.1/TX; also elsewhere on the board
L3_TX: U$1.0/RX; also elsewhere on the board
L4_RX: U$1.10/CS; also elsewhere on the board
L4_TX: U$1.9/CS; also elsewhere on the board
LIGHT_INT: U$1.39/A20; also elsewhere on the board
unnamed: JP1.1, U$1.VIN
unnamed: JP2.1, U$1.3V3_LO
unnamed: R4.1, S1.11, U$1.25
unnamed: 2C3.2, 2D1.C, 2L1.P1 (1), 2U1.8 (PH)
unnamed: 2R1.1, 2R2.2, 2U1.4 (VSNS)
unnamed: 2C3.1, 2U1.1 (BOOT)
unnamed: RPI_POWER.2, S2.2
unnamed: R3.1, S1.12, U$1.24
unnamed: R5.1, S1.10, U$1.26
unnamed: R8.1, S1.9, U$1.27
unnamed: R11.2, RPI_UART.4
unnamed: D1.A, R11.1
PWMM1: U$1.35/A16; also elsewhere on the board
PWMM2: U$1.36/A17; also elsewhere on the board
PWMM3: U$1.37/A18; also elsewhere on the board
PWMM4: U$1.38/A19; also elsewhere on the board
RPI_1: R10.1, RPI_UART.2, S1.7
RPI_2: R9.1, RPI_UART.1, S1.8
RPI_RX: RPI_UART.5, U$1.32/A13
RPI_TX: RPI_UART.6, U$1.31/A12


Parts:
1C1, 1C2, 1C3, 1C4: 1uF; C0603
1C5, 1C6: 20pF; C0603
1D1: BLUE; LED-0603
1OSC: 8MHz; CRYSTAL-SMD-5X3.2-2PAD
1R1, 1R3: 1k; R0603
1R2, 1R4: 10k; R0603
1SW1: MOMENTARY_SWITCH_4X3
1U1: STM32F103CBT6; LQFP48
J2: CONN_03; 1X03_LOCK
J5: CONN_05LOCK; 1X05_LOCK
S3: SWITCH-SPDT-PTH-11.6X4.0MM-LOCK; SWITCH_SPDT_PTH_11.6X4.0MM_LOCK
SWD: SM06B-SRSS-TB
X1: BM10B-SRSS-TB

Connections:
3.3V: J2.3, J5.4, S3.1 (O); also elsewhere on the board
3.3V_MCU: 1C1.1, 1C2.1, 1C3.1, 1C4.1, 1R2.2, 1U1.9 (VDD_A), 1U1.24 (VDD_1), 1U1.36 (VDD_2), 1U1.48 (VDD_3), S3.2; also elsewhere on the board
3.3V_PROG: S3.3 (S), SWD.4
5V: J5.5; also elsewhere on the board
33: 1R1.2, 1U1.19 (PB1/ADC12_IN9/TIM3_CH4)
DEBUG_RX: 1U1.13 (PA3/USART2_RX/ADC12_IN3/TIM2_CH4), SWD.6
DEBUG_TX: 1U1.12 (PA2/USART2_TX/ADC12_IN2/TIM2_CH3), SWD.5
GND: 1C1.2, 1C2.2, 1C3.2, 1C4.2, 1C5.2, 1C6.2, 1D1.C, 1R3.1, 1R4.2, 1U1.8 (VSS_A), 1U1.23 (VSS_1), 1U1.35 (VSS_2), 1U1.47 (VSS_3), J2.2, J5.1, SWD.1; also elsewhere on the board
IMU_RST: 1U1.2 (PC13-TAMPER-RTC); also elsewhere on the board
IMU_SCL: 1U1.42 (PB6/I2C1_SCL/TIM4_CH1); also elsewhere on the board
IMU_SDA: 1U1.43 (PB7/I2C1_SDA/TIM4_CH2); also elsewhere on the board
INM1: X1.8; also elsewhere on the board
INM2: X1.6; also elsewhere on the board
INM3: X1.4; also elsewhere on the board
INM4: X1.2; also elsewhere on the board
L1_RX: X1.9; also elsewhere on the board
L1_TX: X1.10; also elsewhere on the board
L3_RX: 1U1.31 (PA10/USART1_RX/TIM1_CH3); also elsewhere on the board
L3_TX: 1U1.30 (PA9/USART1_TX/TIM1_CH2); also elsewhere on the board
L4_RX: J5.2; also elsewhere on the board
L4_TX: J5.3; also elsewhere on the board
LIGHT_INT: J2.1; also elsewhere on the board
unnamed: 1D1.A, 1R1.1
unnamed: 1R3.2, 1SW1.P$1 (1)
unnamed: 1R4.1, 1U1.44 (BOOT0)
OSC_IN: 1C5.1, 1OSC.P$2 (2), 1U1.5 (PD0-OSC_IN)
OSC_OUT: 1C6.1, 1OSC.P$1 (1), 1U1.6 (PD1-OSC_OUT)
PWMM1: X1.7; also elsewhere on the board
PWMM2: X1.5; also elsewhere on the board
PWMM3: X1.3; also elsewhere on the board
PWMM4: X1.1; also elsewhere on the board
RESET: 1R2.1, 1SW1.P$2 (2), 1U1.7 (NRST)
SWDCLK: 1U1.37 (PA14/JTCK/SWCLK), SWD.2
SWDIO: 1U1.34 (PA13/JTMS/SWDIO), SWD.3
VBAT: 1U1.1 (VBAT)



Board: 2 copper layers, 180.0 x 187.8 mm, 59 parts (2 on the bottom side), 54 nets.

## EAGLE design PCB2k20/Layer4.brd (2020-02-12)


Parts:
AC1, AC2, AC3, AC4, AC5, AC6, AC7, AC8: 0.1uF; C0603
C1, C3, C5, C7, C9, C11, C13, C15: 0.1uF; C0603
D1, D2, D3, D4, D5, D6, D7, D8, D9, D10, D11, D12, D13, D14, D15, D16: WS2812B

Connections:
5V: AC1.1, AC2.1, AC3.1, AC4.1, AC5.1, AC6.1, AC7.1, AC8.1, C1.1, C3.1, C5.1, C7.1, C9.1, C11.1, C13.1, C15.1, D1.1 (VDD), D2.1 (VDD), D3.1 (VDD), D4.1 (VDD), D5.1 (VDD), D6.1 (VDD), D7.1 (VDD), D8.1 (VDD), D9.1 (VDD), D10.1 (VDD), D11.1 (VDD), D12.1 (VDD), D13.1 (VDD), D14.1 (VDD), D15.1 (VDD), D16.1 (VDD); also elsewhere on the board
GND: AC1.2, AC2.2, AC3.2, AC4.2, AC5.2, AC6.2, AC7.2, AC8.2, C1.2, C3.2, C5.2, C7.2, C9.2, C11.2, C13.2, C15.2, D1.3 (VSS), D2.3 (VSS), D3.3 (VSS), D4.3 (VSS), D5.3 (VSS), D6.3 (VSS), D7.3 (VSS), D8.3 (VSS), D9.3 (VSS), D10.3 (VSS), D11.3 (VSS), D12.3 (VSS), D13.3 (VSS), D14.3 (VSS), D15.3 (VSS), D16.3 (VSS); also elsewhere on the board
unnamed: D1.2 (DO), D2.4 (DI)
unnamed: D2.2 (DO), D3.4 (DI)
unnamed: D3.2 (DO), D4.4 (DI)
unnamed: D4.2 (DO), D5.4 (DI)
unnamed: D5.2 (DO), D6.4 (DI)
unnamed: D6.2 (DO), D7.4 (DI)
unnamed: D7.2 (DO), D8.4 (DI)
unnamed: D8.2 (DO), D9.4 (DI)
unnamed: D9.2 (DO), D10.4 (DI)
unnamed: D10.2 (DO), D11.4 (DI)
unnamed: D11.2 (DO), D12.4 (DI)
unnamed: D12.2 (DO), D13.4 (DI)
unnamed: D13.2 (DO), D14.4 (DI)
unnamed: D14.2 (DO), D15.4 (DI)
unnamed: D15.2 (DO), D16.4 (DI)
WS2812B_OUT: D1.4 (DI); also elsewhere on the board


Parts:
1C1, 1C3, 1C4, 1C11: 1uF; C0603
1C2: 0.1uF; C0603
1C7, 1C8: 20pF; C0603
1D1: BLUE; LED-0603
1OSC: 8MHz; CRYSTAL-SMD-5X3.2-2PAD
1R1, 1R5: 1k; R0603
1R4: 10k; R0603
1S2: MOMENTARY_SWITCH_4X3
1U1: STM32F103CBT6; LQFP48
J1, J2: CONN_03; 1X03_LOCK
J3: CONN_05LOCK; 1X05_LOCK
J4, J5, J6, J7: CONN_06LOCK; 1X06_LOCK
R1: 10k; R0603
S1: SWITCH-SPDT-PTH-11.6X4.0MM-LOCK; SWITCH_SPDT_PTH_11.6X4.0MM_LOCK
SWD: SM06B-SRSS-TB
U$1: 74HCT08; SOIC-14

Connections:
3.3V: 1C1.1, 1C3.1, 1C4.1, 1C11.1, 1R4.2, 1U1.9 (VDD_A), 1U1.24 (VDD_1), 1U1.36 (VDD_2), 1U1.48 (VDD_3), J4.3, J5.4, J6.3, J7.4, S1.1 (O), SWD.4
5V: 1C2.1, J3.5, U$1.P2 (I1), U$1.P5 (I1), U$1.P10 (I1), U$1.P14 (P$V+); also elsewhere on the board
21: 1U1.37 (PA14/JTCK/SWCLK), SWD.2
22: 1U1.34 (PA13/JTMS/SWDIO), SWD.3
33: 1R1.2, 1U1.19 (PB1/ADC12_IN9/TIM3_CH4)
DEBUG_RX: 1U1.13 (PA3/USART2_RX/ADC12_IN3/TIM2_CH4), SWD.6
DEBUG_TX: 1U1.12 (PA2/USART2_TX/ADC12_IN2/TIM2_CH3), SWD.5
ESC1_IN: 1U1.29 (PA8/USART1_CK/TIM1_CH1/MCO), U$1.P9 (I0)
ESC1_OUT: J1.3, U$1.P8 (O)
ESC2_IN: 1U1.11 (PA1/USART2_RTS/ADC12_IN1/TIM2_CH2), U$1.P4 (I0)
ESC2_OUT: J2.3, U$1.P6 (O)
GND: 1C1.2, 1C2.2, 1C3.2, 1C4.2, 1C7.2, 1C8.2, 1C11.2, 1D1.C, 1R5.1, 1U1.8 (VSS_A), 1U1.23 (VSS_1), 1U1.35 (VSS_2), 1U1.47 (VSS_3), J1.1, J2.1, J3.1, J4.6, J5.1, J6.6, J7.1, R1.2, SWD.1, U$1.P7 (P$V-); also elsewhere on the board
unnamed: 1D1.A, 1R1.1
unnamed: 1R5.2, 1S2.P$1 (1)
unnamed: 1U1.44 (BOOT0), R1.1
unnamed: J3.4, S1.2
OSC_IN: 1C7.1, 1OSC.P$2 (2), 1U1.5 (PD0-OSC_IN)
OSC_OUT: 1C8.1, 1OSC.P$1 (1), 1U1.6 (PD1-OSC_OUT)
RESET: 1R4.1, 1S2.P$2 (2), 1U1.7 (NRST)
SCL: 1U1.42 (PB6/I2C1_SCL/TIM4_CH1), J4.5, J5.2, J6.5, J7.2
SDA: 1U1.43 (PB7/I2C1_SDA/TIM4_CH2), J4.4, J5.3, J6.4, J7.3
TOF1_GPIO: 1U1.2 (PC13-TAMPER-RTC), J4.2
TOF1_XSHUT: 1U1.3 (PC14-OSC32_IN), J4.1
TOF2_GPIO: 1U1.14 (PA4/SPI1_NSS/USART2_CK/ADC12_IN4), J5.5
TOF2_XSHUT: 1U1.15 (PA5/SPI1_SCK/ADC12_IN5), J5.6
TOF3_GPIO: 1U1.41 (PB5/I2C1_SMBA), J6.2
TOF3_XSHUT: 1U1.40 (PB4/NJTRST), J6.1
TOF4_GPIO: 1U1.39 (PB3/JTDO), J7.5
TOF4_XSHUT: 1U1.38 (PA15/JTDI), J7.6
USART1_RX: 1U1.31 (PA10/USART1_RX/TIM1_CH3), J3.2
USART1_TX: 1U1.30 (PA9/USART1_TX/TIM1_CH2), J3.3
VBAT: 1U1.1 (VBAT)
WS2812B: 1U1.17 (PA7/SPI1_MOSI/ADC12_IN7/TIM3_CH2), U$1.P1 (I0)
WS2812B_OUT: U$1.P3 (O); also elsewhere on the board



Board: 2 copper layers, 94.0 x 94.0 mm, 57 parts (12 on the bottom side), 48 nets.

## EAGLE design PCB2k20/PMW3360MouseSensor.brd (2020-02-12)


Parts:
C1, C2: 1.0uF; 0603
C3: 0.1uF; 0603
C4: 4.7uF; 0603
J1: CONN_08LOCK; 1X08_LOCK
R1: 39; 0603
R2, R3: 10k; 0603
U$1: LN6206; SOT95P237X112-3N
U$2: PMW3360

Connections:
1.8V: C1.1, R1.2, U$1.2 (VOUT), U$2.P4 (VDD)
3.3V: C2.1, J1.1, R2.2, R3.1, U$1.3 (VIN), U$2.P5 (VDDIO)
GND: C1.2, C2.2, C3.1, C4.1, J1.2, U$1.1 (GND), U$2.P8 (GND)
MISO: J1.7, R2.1, U$2.P12 (MISO)
MOSI: J1.8, U$2.P11 (MOSI)
MOT: J1.4, U$2.P9 (MOT)
unnamed: R1.1, U$2.P15 (LED_P)
unnamed: C3.2, C4.2, U$2.P3 (VDDPIX)
NRESET: J1.3, R3.2, U$2.P7 (NRESET)
SCK: J1.6, U$2.P10 (SCLK)
SS: J1.5, U$2.P13 (NCS)


Board: 2 copper layers, 34.6 x 24.0 mm, 10 parts (0 on the bottom side), 11 nets.

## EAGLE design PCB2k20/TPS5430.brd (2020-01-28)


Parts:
C1: 22.0uF; C1210
C2: 4.7uF; C0603
C3: 220uF; D/7343-31R
C4: 0.1uF; C0603
C5: 10.0nF; C0603
D1: 3A/40V/500mV; SMA-DIODE
J1: CONN_03; 1X03_LOCK
JP1: JUMPER-SMT_3_NO_NO-SILK; SMT-JUMPER_3_NO_NO-SILK
L1: SWPA8040/10uH; SWPA8040
R1: 10k; R0603
R2: 5.9k; R0603
R3: 3.24k; R0603
U1: TPS5430; POWERPAD-SOIC-8

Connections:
GND: C1.2, C2.2, C3.-, C4.2, D1.A, J1.2, R2.1, R3.1, U1.6 (GND), U1.9 (GND), U1.P$1 (GND), U1.P$2 (GND), U1.P$3 (GND), U1.P$4 (GND), U1.P$5 (GND), U1.P$6 (GND)
unnamed: JP1.2, R1.1, U1.4 (VSNS)
unnamed: C5.1, U1.1 (BOOT)
unnamed: JP1.3, R2.2
unnamed: JP1.1, R3.2
unnamed: C5.2, D1.C, L1.P1 (1), U1.8 (PH)
VIN: C1.1, C2.1, J1.3, U1.7 (VIN)
VOUT: C3.+, C4.1, J1.1, L1.P2 (2), R1.2



Board: 2 copper layers, 19.0 x 19.0 mm, 13 parts (5 on the bottom side), 8 nets.

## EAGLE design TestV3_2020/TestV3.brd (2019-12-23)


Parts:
1C1, 1C3, 1C4, 1C6, 1C11: 1uF; C0603
1C2: 10nF; C0603
1C5: 4.7uF; C0603
1C7, 1C8: 20pF; C0603
1C9, 1C10: 47pF; C0603
1D1: BLUE; LED-0603
1FB1, 1FB2: 30Ω/1.8A; 0603
1J1: USB-MICROB
1J2, 1J3: CONN_20LOCK; 1X20_LOCK
1OSC: 8MHz; CRYSTAL-SMD-5X3.2-2PAD
1Q1, 1Q2: 600mA/40V; SOT23-3
1R1, 1R2, 1R5, 1R6: 1k; R0603
1R3, 1R4, 1R9: 10k; R0603
1R7, 1R8: 22; R0603
1R10: 1.5k; R0603
1R11: 36k; R0603
1R12: 47k; R0603
1S1, 1S2: 34-MOMENTARY-SWITCH; 3*4-MOMENTARY-SWITCH
1U1: STM32F103CBT6; LQFP48
1U2: V_REG_LM1117SOT223; SOT223
SWD: CONN_04LOCK; 1X04_LOCK

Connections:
0: 1J2.2, 1U1.22 (PB11/I2C2_SDA/USART3_RX)
1: 1J2.3, 1U1.21 (PB10/I2C2_SCL/USART3_TX)
2: 1J2.4, 1U1.20 (PB2/BOOT1)
3: 1J2.5, 1U1.18 (PB0/ADC12_IN8/TIM3_CH3)
4: 1J2.6, 1U1.17 (PA7/SPI1_MOSI/ADC12_IN7/TIM3_CH2)
5: 1J2.7, 1U1.16 (PA6/SPI1_MISO/ADC12_IN6/TIM3_CH1)
6: 1J2.8, 1U1.15 (PA5/SPI1_SCK/ADC12_IN5)
7: 1J2.9, 1U1.14 (PA4/SPI1_NSS/USART2_CK/ADC12_IN4)
8: 1J2.10, 1U1.13 (PA3/USART2_RX/ADC12_IN3/TIM2_CH4)
9: 1J2.11, 1U1.12 (PA2/USART2_TX/ADC12_IN2/TIM2_CH3)
10: 1J2.12, 1U1.11 (PA1/USART2_RTS/ADC12_IN1/TIM2_CH2)
11: 1J2.13, 1U1.10 (PA0_WKUP/USART2_CTS/ADC12_IN0/TIM2_CH1_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)
12: 1J2.15, 1U1.4 (PC15-OSC32_OUT)
13: 1J2.16, 1U1.3 (PC14-OSC32_IN)
14: 1J2.17, 1U1.2 (PC13-TAMPER-RTC)
15: 1J3.4, 1U1.43 (PB7/I2C1_SDA/TIM4_CH2)
16: 1J3.5, 1U1.42 (PB6/I2C1_SCL/TIM4_CH1)
17: 1J3.6, 1U1.41 (PB5/I2C1_SMBA)
18: 1J3.7, 1U1.40 (PB4/NJTRST)
19: 1J3.8, 1U1.39 (PB3/JTDO)
20: 1J3.9, 1U1.38 (PA15/JTDI)
21: 1J3.10, 1U1.37 (PA14/JTCK/SWCLK), SWD.2
22: 1J3.11, 1U1.34 (PA13/JTMS/SWDIO), SWD.3
23_USBDP: 1C10.2, 1J3.12, 1R7.1, 1R10.1, 1U1.33 (PA12/USART1_RTS/CAN_TX/TIM1_ETR/USBDP)
24_USBDM: 1C9.2, 1J3.13, 1R8.1, 1U1.32 (PA11/USART1_CTS/CAN_RX/TIM1_CH4/USBDM)
25: 1J3.14, 1U1.31 (PA10/USART1_RX/TIM1_CH3)
26: 1J3.15, 1U1.30 (PA9/USART1_TX/TIM1_CH2)
27: 1J3.16, 1U1.29 (PA8/USART1_CK/TIM1_CH1/MCO)
28: 1J3.17, 1U1.28 (PB15/SPI2_MOSI/TIM1_CH3N)
29: 1J3.18, 1U1.27 (PB14/SPI2_MISO/USART3_RTS/TIM1_CH2N)
30: 1J3.19, 1U1.26 (PB13/SPI2_SCK/USART3_CTS/TIM1_CH1N)
31: 1J3.20, 1U1.25 (PB12/SPI2_NSS/I2C2_SMBA/USART3_CK/TIM1_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)
32: 1J3.3, 1R3.2, 1S1.P2 (2), 1U1.44 (BOOT0), 1U1.45 (PB8/TIM4_CH3)
33: 1R1.2, 1U1.19 (PB1/ADC12_IN9/TIM3_CH4)
AGND: 1C1.2, 1C2.2, 1FB2.2, 1J2.19, 1U1.8 (VSS_A)
DISC: 1R6.1, 1U1.46 (PB9/TIM4_CH4)
GND: 1C3.2, 1C4.2, 1C5.2, 1C6.2, 1C7.2, 1C8.2, 1C9.1, 1C10.1, 1C11.2, 1D1.C, 1FB2.1, 1J1.GND, 1J3.2, 1Q1.2 (E), 1R3.1, 1R5.1, 1R11.1, 1U1.23 (VSS_1), 1U1.35 (VSS_2), 1U1.47 (VSS_3), 1U2.1 (ADJ), SWD.1
unnamed: 1R2.1, 1S1.P1 (1)
unnamed: 1D1.A, 1R1.1
unnamed: 1R5.2, 1S2.P1 (1)
unnamed: 1Q2.2 (E), 1R10.2
unnamed: 1J1.D-, 1R8.2
unnamed: 1J1.D+, 1R7.2
unnamed: 1Q1.3 (C), 1Q2.1 (B), 1R9.1, 1R11.2
unnamed: 1Q1.1 (B), 1R6.2, 1R12.1
OSC_IN: 1C7.1, 1OSC.P$2 (2), 1U1.5 (PD0-OSC_IN)
OSC_OUT: 1C8.1, 1OSC.P$1 (1), 1U1.6 (PD1-OSC_OUT)
RESET: 1J2.14, 1R4.1, 1S2.P2 (2), 1U1.7 (NRST)
VBAT: 1J2.18, 1U1.1 (VBAT)
VCC: 1C3.1, 1C4.1, 1C6.1, 1C11.1, 1FB1.1, 1J3.1, 1Q2.3 (C), 1R2.2, 1R4.2, 1R12.2, 1U1.24 (VDD_1), 1U1.36 (VDD_2), 1U1.48 (VDD_3), 1U2.2 (OUT), 1U2.4 (OUT), SWD.4
VCCA: 1C1.1, 1C2.1, 1FB1.2, 1J2.20, 1U1.9 (VDD_A)
V_USB: 1C5.1, 1J1.VBUS, 1R9.2, 1U2.3 (IN)

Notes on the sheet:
BOOT0
use xh2.54 here


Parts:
2C1, 4C2: 4.7uF; C0603
2C2: 10uF; C0603
2C3: 33pF; C0603
2C4, 3C5, 4C5: 0.1uF; C0603
2D1, 4D1: SS34; SMA-DIODE
2L1: 3.3uH; SWPA4030
2R1: 40.2k; R0603
2R2: 124k; R0603
2R3: 39k; R0603
2R4, 3R3: 20k; R0603
3C1: 100uF; PANASONIC_D
3C2: 1uF; C0603
3C3: 100uF; NIC_10X10.5_CAP
3D1: SS510; SMB
3L1: 56uH; CDRH127
3POT1: 10k; 3296-TRIMPOT
3R1: 2.94k; R0603
3R2: 1.5k; R0603
3R4: 47k; R0603
3U1: LM2587; TO-263
4C1: 22uF; C1210
4C3, 4C8: 10nF; C0603
4C6, 4C7: 47uF; C1206
4C9: 1nF; C0603
4C10: 47pF; C0603
4C11: 4700pF; C0603
4C12: 39pF; C0603
4JP1, 4JP2: JUMPER-SMT_3_NO_NO-SILK; SMT-JUMPER_3_NO_NO-SILK
4L1: 6.8uH; SWPA8040
4R1: 180k; R0603
4R2: 51k; R0603
4R3: 10k; R0603
4R4: 29.4k; R0603
4R5: 49.9k; R0603
4R6: 3.24k; R0603
4R7: 1.91k; R0603
J2: CONN_05LOCK; 1X05_LOCK
J5, J11: CONN_03; 1X03_LOCK
J10: CONN_03-SCREW-5MM; SCREWTERMINAL-5MM-3
JP1: JUMPER-SMT_2_NO_NO-SILK_ROUND; SMT-JUMPER_2_NO_NO-SILK_ROUND
U1: TPS54X31; POWERPAD-SOIC-8
U2: MP2451; SOT23-6-MP
U3: MCP41XXX; SOIC-8

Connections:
COMP: 4JP1.2, U1.6 (COMP)
FDBK: 3POT1.1 (CCW), 3POT1.2 (WIPER), 3R2.2, 3R3.1, 3U1.P2 (FDBK)
GND-BOOST: 3C1.-, 3C2.2, 3C3.-, 3R2.1, 3U1.P3 (GND), 3U1.P$1 (GND), 3U1.P$2 (GND), 3U1.P$3 (GND), 3U1.P$4 (GND), 3U1.P$5 (GND), 3U1.P$6 (GND), 3U1.P$7 (GND), 3U1.P$8 (GND), 3U1.P$9 (GND), 3U1.P$10 (GND), 3U1.P$11 (GND), 3U1.P$12 (GND), 3U1.P$13 (GND), 3U1.P$14 (GND), 3U1.P$15 (GND), 3U1.P$16 (GND), 3U1.P$17 (GND), 3U1.P$18 (GND), 3U1.P$19 (GND), 3U1.P$20 (GND), 3U1.TAB (GND), J10.2, JP1.1
GND-BUCK: 2C1.2, 2C2.2, 2D1.A, 2R1.1, 2R4.1, J11.2, U2.P2 (GND)
GND-ISO: 4C1.2, 4C2.2, 4C3.2, 4C6.2, 4C7.2, 4C8.2, 4C10.2, 4C12.2, 4D1.A, 4R2.1, 4R4.2, 4R5.2, 4R6.1, 4R7.1, J5.2, U1.7 (GND), U1.9 (GND), U1.P$1 (GND), U1.P$2 (GND), U1.P$3 (GND), U1.P$4 (GND), U1.P$5 (GND), U1.P$6 (GND)
GND-POT: 3C5.2, J2.2, JP1.2, U3.4 (GND)
unnamed: 2C3.2, 2R1.2, 2R2.1, U2.P3 (FB)
unnamed: 2C4.2, 2D1.C, 2L1.P1 (1), U2.P6 (SW)
unnamed: 2C4.1, U2.P1 (BST)
unnamed: 4C8.1, U1.4 (SS)
unnamed: 4C5.1, U1.1 (BOOT)
unnamed: 4C5.2, 4D1.C, 4L1.P1 (1), U1.8 (PH)
unnamed: 4R1.1, 4R2.2, U1.3 (EN)
unnamed: 4C9.2, 4R4.1
unnamed: 4C9.1, 4C10.1, 4JP1.1
unnamed: 3POT1.3 (CW), U3.5 (CCW), U3.6 (WIPER)
unnamed: 3R3.2, 3R4.1, U3.7 (CW)
unnamed: 2R3.2, 2R4.2, U2.P4 (EN)
unnamed: J2.3, U3.3 (MOSI)
unnamed: J2.4, U3.2 (SCLK)
unnamed: J2.5, U3.1 (CS)
unnamed: 3D1.A, 3L1.2, 3U1.P4 (SW)
unnamed: 3R1.2, 3U1.P1 (COMP)
unnamed: 3C2.1, 3R1.1
unnamed: 4C11.2, 4R5.1
unnamed: 4C11.1, 4C12.1, 4JP1.3
unnamed: 4JP2.1, 4R6.2
unnamed: 4JP2.3, 4R7.2
VIN: 4C1.1, 4C2.1, 4C3.1, 4R1.2, J5.3, U1.2 (VIN)
VIN-BOOST: 3C1.+, 3L1.1, 3U1.P5 (VIN), J10.3
VIN-BUCK: 2C1.1, 2R3.1, J11.3, U2.P5 (VIN)
VIN-POT: 3C5.1, J2.1, U3.8 (VCC)
VOUT: 4C6.1, 4C7.1, 4L1.P2 (2), 4R3.2, J5.1
VOUT-BOOST: 3C3.+, 3D1.C, 3R4.2, J10.1
VOUT-BUCK: 2C2.1, 2C3.1, 2L1.P2 (2), 2R2.2, J11.1
VSNS: 4JP2.2, 4R3.1, U1.5 (VSNS)

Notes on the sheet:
MAX 5v!!!!


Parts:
C13: 2.2uF; C0603
C14: 10nF/16V; C0603
C15, C16: 10uF; C0805; VOLTAGE 16V
C20: 0.1uF; C0603
CS1: TCS3200; SOIC-8
D1, D2, D3, D4, D5, D7: 3528LED; 3528
D6: BLUE; LED-0603
J1, J7: CONN_07LOCK; 1X07_LOCK
J3: CONN_08LOCK; 1X08_LOCK
J4, J6: XT30UPB-F
J8: CONN_025MM; SCREWTERMINAL-5MM-2
J9, J12: CONN_02LOCK; 1X02_LOCK
J13: XT60PB-F
Q3, Q4: 600mA/40V; SOT23-3
R22: 3.6k; R0603
R23: 75k; R0603
R24, R29: 100k; R0603
R25: 560; R0603
R26, R27: 0.2; R0603
R28: 47k; R0603
R30: 10k; R0603
U4, U6, U7, U8: LIGHT_SENSORALS; ALS-PT19
U5: DRV8833; SSOP16

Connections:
GND-CS: C20.1, CS1.4 (GND), J1.2, R30.1
GND-LED: J9.1, Q3.2 (E), Q4.2 (E), R22.1
GND-MOTOR: C13.2, C15.2, C16.2, J8.1, R26.1, R27.1, U5.13 (GND), U5.PPAD (GND)
unnamed: D1.A, D2.A, D3.A, D4.A, D5.A, D7.A, J12.2
unnamed: D1.C, D2.C, D3.C, D4.C, D5.C, D7.C, J12.1
unnamed: J3.2, U4.C (C1)
unnamed: J3.1, U4.E (E1)
unnamed: J3.4, U6.C (C1)
unnamed: Q3.3 (C), Q4.1 (B), R24.1
unnamed: D6.A, R25.2
unnamed: D6.C, Q4.3 (C)
unnamed: J7.7, U5.16 (A-IN1)
unnamed: Q3.1 (B), R22.2, R23.1
unnamed: J7.6, U5.15 (A-IN2)
unnamed: J7.5, U5.9 (B-IN1)
unnamed: J7.4, U5.10 (B-IN2)
unnamed: J7.3, R28.1, U5.1 (SLEEP)
unnamed: J7.2, R29.1, U5.8 (FAULT)
unnamed: R26.2, U5.6 (B-ISEN)
unnamed: R27.2, U5.3 (A-ISEN)
unnamed: J4.+ (P$V+), U5.2 (A-OUT1)
unnamed: J4.- (P$V-), U5.4 (A-OUT2)
unnamed: J6.+ (P$V+), U5.7 (B-OUT1)
unnamed: J6.- (P$V-), U5.5 (B-OUT2)
unnamed: C14.1, U5.11 (VCP)
unnamed: C13.1, U5.14 (VINT)
unnamed: CS1.1 (S0), J1.7
unnamed: CS1.2 (S1), J1.6
unnamed: CS1.7 (S2), J1.5
unnamed: CS1.8 (S3), J1.4
unnamed: CS1.6 (OUT), J1.3
unnamed: CS1.3 (OE), R30.2
unnamed: J3.3, U6.E (E1)
unnamed: J3.8, U7.C (C1)
unnamed: J3.7, U7.E (E1)
unnamed: J3.5, U8.E (E1)
unnamed: J3.6, U8.C (C1)
VCC-MOTOR: J7.1, R28.2, R29.2
VIN-CS: C20.2, CS1.5 (VIN), J1.1
VIN-LED: J9.2, R23.2, R24.2, R25.1
VIN-MOTOR: C14.2, C15.1, C16.1, J8.2, U5.12 (VM)

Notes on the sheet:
PWM Pins!!
MAX 10v!!
3.3v!



Board: 2 copper layers, 100.0 x 100.0 mm, 127 parts (38 on the bottom side), 129 nets.

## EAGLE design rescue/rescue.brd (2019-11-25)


Board: 2 copper layers, 100.0 x 100.0 mm, 36 parts (0 on the bottom side), 22 nets, no tracks yet.

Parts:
BUT: KMR211GLFS; PUSHBUTTON-KMR241GLFS
C1: 100uF; EIA3216
C2, C3: 10uF; 0805
C4, C5, C6, C7: 1uF; C0402
C8, C9: 18pF; C0402
C10, C11: 47pF; C0402
D1: Blue; LED-1206
D2: SOD-323
IC1, IC2: MCP1703T-3302E/CB; SOT23
J3: USB_B_PTH; USB-B-PTH
L1: ferrite bead; 0603
OSC: 8MHz; CRYSTAL-SMD-5X3
Q1, Q2: NPN-BJT; SOT23
R1, R2, R4, R5: 1k; C0402
R3, R8, R9: 10k; C0402
R6, R7: 22; C0402
R10: 1.5k; C0402
R11: 36k; C0402
R12: 47k; C0402
RESET: KMR211GLFS; PUSHBUTTON-KMR241GLFS
U$1: TB6612FNG; SSOP24
UC1: STM32F103CBT6; LQFP48

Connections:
12V: C1.A, D2.1, IC1.3, IC2.3
23_USBDP: C11.2, R7.1, R10.1, UC1.33
24_USBDM: C10.2, R6.1, UC1.32
32: BUT.P$2, BUT.P$4, R9.2, UC1.44, UC1.45
33: R1.2, UC1.19
AV-: C3.2, C4.2, IC2.1, L1.1, UC1.8
DISC: R5.1, UC1.46
GND: C1.C, C2.2, C5.2, C6.2, C7.2, C8.2, C9.2, C10.1, C11.1, D1.C, IC1.1, J3.GND, L1.2, Q1.2, R4.1, R9.1, R11.1, UC1.23, UC1.35, UC1.47
unnamed: BUT.P$1, BUT.P$3, R2.1
unnamed: D1.A, R1.1
unnamed: R4.2, RESET.P$1, RESET.P$3
unnamed: Q2.2, R10.2
unnamed: J3.D-, R6.2
unnamed: J3.D+, R7.2
unnamed: Q1.3, Q2.1, R8.1, R11.2
unnamed: Q1.1, R5.2, R12.1
OSC_IN: C9.1, OSC.3, UC1.5
OSC_OUT: C8.1, OSC.1, UC1.6
RESET: R3.1, RESET.P$2, RESET.P$4, UC1.7
VCC: C2.1, C5.1, C6.1, C7.1, IC1.2, Q2.3, R2.2, R3.2, R12.2, UC1.24, UC1.36, UC1.48
VCCA: C3.1, C4.1, IC2.2, UC1.9
V_USB: D2.2, J3.VBUS, R8.2

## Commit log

2019-11-25 reorganising and add test pcb
    [TestV3.sch, rescue.brd, rescue.sch]
2019-11-26 minor change
    [TestV3.sch]
2019-11-26 don't track eagle.epf files
2019-11-26 Finished schematic of buck converters will make changes to the values of compensation components to make them more standard values
    [TestV3.brd, TestV3.sch]
2019-11-27 shift buck converters to own library rcl
    [TestV3.sch]
2019-12-10 Added Datasheets folder and cleaned up the schematic to use less random libraries
    [TestV3.brd, TestV3.sch]
2019-12-10 Small changes to STM32: Added protection diodes between V_USB and VCC, and added ferrite beads to filter analog voltage
    [TestV3.brd, TestV3.sch]
2019-12-11 Don't track EAGLE backup files
2019-12-13 IDK what I did but added datasheet of INA20x current shunt controller cuz will be using that
    [TestV3.brd, TestV3.sch]
2019-12-13 Rearranged datasheet folder and deleted unused ones Also added BD2244 Power Load Switch IC (For short circuit protection)
2019-12-13 Finally finished LM2587 Boost Circuit, together with INA169+LM393 overcurrent protection
    [TestV3.brd, TestV3.sch]
2019-12-18 Finished low battery detection, motor driver and TCS3200 color sensor.
    [TestV3.brd, TestV3.sch]
2019-12-18 Finished TPS54331 Buck Converter Board Layout and Isolation Final Size ~2.2*2.2cm But I should probably add some test points and fix the silkscreen
    [TestV3.brd, TestV3.sch]
2019-12-19 Added TCS3200 Datasheet and updated buck converter board layout fixed the silkscreen for buck converter and finalise design
    [TestV3.brd, TestV3.sch]
2019-12-19 finished stm32 board layout, the end is near!
    [TestV3.brd, TestV3.sch]
2019-12-20 MP2451 Buck Converter Circuit
    [TestV3.brd, TestV3.sch]
2019-12-20 Fixed silkscreen for stm32 and mp2541
    [TestV3.brd]
2019-12-20 finished all the board layouts
    [TestV3.brd, TestV3.sch]
2019-12-20 added more light sensors and lights to test and optimise positioning, added xt60 for test fitting
    [TestV3.brd, TestV3.sch]
2019-12-23 minor changes, mostly fixed the values of some components
    [TestV3.brd, TestV3.sch]
2019-12-29 Mouse Sensor Socket because $10 sensors should be reused
    [PMW3360MouseSensor.brd, PMW3360MouseSensor.dxf, PMW3360MouseSensor.sch]
2019-12-29 Make the screws not hit the lens
    [PMW3360MouseSensor.brd, PMW3360MouseSensor.dxf]
2020-01-21 Finalise PMW3360 breakout - done pin markings and cleanup - swapped position of some pins to route stuff more easily
    [PMW3360MouseSensor.brd, PMW3360MouseSensor.dxf, PMW3360MouseSensor.sch]
2020-01-21 IR and ESC datasheets
2020-01-22 Start on layer 4: WS2812B and STM32
    [Layer4.brd, Layer4.sch]
2020-01-27 Layer 4: linked with fusion so its easier to move stuff around
    [Layer4.brd, Layer4.sch]
2020-01-27 add ws2812b rgb led datasheet
2020-01-28 TPS54331 didnt really work because china, so we are using the TPS5430 now..
    [TPS5430.brd, TPS5430.sch]
2020-01-30 finish layer 4 and start on layer 3, TODO: silkscreen for layer4
    [Layer3.sch, Layer4.brd, Layer4.sch]
2020-02-02 no idea what i did but need to save this so
    [Layer1.brd, Layer1.sch, Layer3.brd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]
2020-02-02 Layer 3 placement kinda done, routing to wait for layer 1 signals to be confirmed. also renamed some folders because windows explorer doesnt like the old name
    [Layer1.brd, Layer1.sch, Layer3.brd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]
2020-02-03 continue on layer 1 schematic, just need to finish this asap and quickly start positioning
    [Layer1.brd, Layer1.sch, Layer3.brd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]
2020-02-06 added a switch to choose between programmer power and battery power for STM32
    [Layer3.brd, Layer3.sch]
2020-02-08 placement done wow that was difficult
    [Layer1.brd, Layer1.sch]
2020-02-08 half routed
    [Layer1.brd, Layer1.sch]
2020-02-10 done just need to silkscreen now!!!
    [Layer1.brd, Layer1.sch, Layer3.brd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]
2020-02-12 add gerbers, please everything turn out well!
    [Layer1.brd, Layer1.sch, Layer3.brd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]
2020-02-19 update values
    [Layer1.brd, Layer1.sch, Layer3.brd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]
2020-02-23 Change pullup resistor to value we alr have
    [Layer1.brd, Layer1.sch, RescueLS.brd]
2020-03-19 Welp I should go kms dumb mistakes time for Rescue PCB V2
    [RescueLS.brd, RescueLS.sch]
2020-06-27 add schematic PDFs

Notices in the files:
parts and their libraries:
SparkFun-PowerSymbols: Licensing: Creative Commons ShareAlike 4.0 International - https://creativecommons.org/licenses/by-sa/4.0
